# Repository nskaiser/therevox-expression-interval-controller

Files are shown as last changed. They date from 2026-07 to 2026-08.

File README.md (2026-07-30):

# Therevox Expression Controller

Turns an expression pedal input into a programmable Therevox modulation source. In `PED` mode, pick a pitch-bend interval with the rotary encoder and the pedal bends smoothly from no-bend to that interval; in `LO`/`FM` modes, the expression output can become an LFO source. The MCP4728 build also adds two independent 3.5mm LFO outputs for the Therevox patch panel.

Built with:

- Raspberry Pi Pico H
- MCP4728 quad I2C DAC
- 0.91 inch 128x32 I2C OLED
- Rotary encoder with push switch
- Two 1/4 inch TRS jacks: expression pedal in, Therevox expression/CV out
- Two 3.5mm TS jacks: independent LFO 1 and LFO 2 outputs
- USB power

## Start Here

| Need | File |
| --- | --- |
| Arduino firmware | `pico/PrecisionExpressionControllerPico/PrecisionExpressionControllerPico.ino` |
| User/menu manual | `docs/user-manual.md` |
| Therevox sample patches | `docs/sample-patches.md` |
| Wiring and bench test | `docs/pico-prototype.md` |
| Perfboard/enclosure layout | `docs/pico-physical-layout.md` |
| BOM | `docs/bom.md` |
| Console simulator | `sim/pico_console_sim.cpp` |
| 3D-print enclosure files (untested, never printed) | `hardware/enclosure/` |

## How It Works

One bend direction is active at a time for the expression output. Use the menu or serial `direction up|down` to change it.

```text
UP:   heel 0 V, toe rises to the selected interval's voltage
DOWN: heel 3.3 V, toe falls to the selected interval's voltage
```

Tune the instrument with the pedal at heel.

Interval accuracy comes from a per-interval voltage map. Set the overall scale with `response <cents>` (the pitch change your instrument produces at full DAC scale; `3960` for a true 1V/oct input), then fine-tune any interval against a tuner with `tune on`. See `docs/pico-prototype.md` for the full serial command reference.

Note the DAC output tops out at 3.3 V. If your instrument needs more than that for an octave, the largest selectable interval shrinks accordingly.

LFO modes ignore the pedal interval map and output a unipolar `0-3.3V` modulation signal from the DAC. `LO` covers slow LFO rates (`0.05-20 Hz`); `FM` covers faster modulation rates (`8-160 Hz`). On the expression output, the pedal sweeps LFO speed from slow to fast and the encoder adjusts depth. On `LFO1`/`LFO2`, the encoder adjusts speed directly.

LFO features:

- Eight waveforms: sine, triangle, saw up, saw down, square, pulse (adjustable width `5-95%`), sample+hold random, and drift (smoothed random).
- Depth `0-100%` around the midpoint, plus a `-50..+50%` center offset on `LFO1`/`LFO2` (depth `0` + offset = fixed CV).
- `LFO2` can lock to `LFO1` at a rate ratio (`1:1`, `1:2`, `1:4`, `3:2`, `2:1`, `4:1`) with a `0/90/180/270` degree phase offset — quadrature and polyrhythm pairs that never drift.
- Tap tempo: two short presses on a focused LFO sync it and set its rate to the tapped interval.
- `sync` / `sync all` phase resets, per-output polarity.
- The DAC's fourth channel can emit a full-swing clock square at `LFO1` or `LFO2`'s rate (`clock lfo1|lfo2`).

## Build And Upload

1. In Arduino IDE, install the board package `Raspberry Pi Pico/RP2040/RP2350` by Earle F. Philhower.
2. Open `pico/PrecisionExpressionControllerPico/PrecisionExpressionControllerPico.ino`.
3. Select `Tools > Board > Raspberry Pi Pico/RP2040/RP2350 > Raspberry Pi Pico`.
4. Plug in the Pico over USB, select its port, and upload.
5. Open Serial Monitor at `115200`.

If the Pico does not show as a port, unplug it, hold `BOOTSEL`, plug USB back in, release `BOOTSEL`, then upload again.

## Tests

```bash
# Host math test
g++ -std=c++17 test/test_pico_core.cpp -o /tmp/expctrl_test && /tmp/expctrl_test

# Console simulator (expects SIM RESULT: PASS)
g++ -std=c++17 sim/pico_console_sim.cpp -o /tmp/expctrl_sim && /tmp/expctrl_sim

# Firmware compile check
arduino-cli compile --fqbn rp2040:rp2040:rpipico pico/PrecisionExpressionControllerPico
```

## Control Summary

| Action | Result |
| --- | --- |
| Turn encoder with `EXP` focused in `PED` | Change interval size by one semitone |
| Move pedal in expression `LO`/`FM` | Sweep expression-output LFO speed within that mode's range |
| Turn encoder with `EXP` focused in `LO`/`FM` | Change expression-output LFO depth/attenuation in `5%` steps |
| Turn encoder with `LFO1` or `LFO2` focused | Change that dedicated LFO output speed (or phase offset when `LFO2` is linked) |
| Short press in `PED` | Reset interval to unison |
| Short press in `LO`/`FM`, `LFO1`, or `LFO2` | Sync the focused LFO; two presses at tempo tap its rate |
| Double-click | Cycle edit focus: `EXP` -> `LFO1` -> `LFO2` |
| Hold ~2s | Open menu |
| In menu: turn / press / hold ~2s | Scroll items / edit or choose / exit |
| Editing a menu value | Turn to the value you want, then press to save |

Settings autosave about 3s after the last change.

See `docs/user-manual.md` for the full OLED menu reference.

LFO serial shortcuts:

```text
mode ped|lo|fm
focus exp|lfo1|lfo2
wave sine|tri|sawup|sawdown|square|pulse|sh|drift
rate 1.5      set focused LFO speed; EXP LFO uses this as toe/max speed
depth 75      set focused LFO depth, 0..100
pw 60         pulse-wave width, 5..95
offset -25    shift focused LFO1/LFO2 center, -50..50
link 1:2      lock LFO2 rate to LFO1; link phase 90 for quadrature
clock lfo1    full-swing clock square on the DAC's spare channel
sync          sync focused LFO; sync all resets every phase
tap           send twice at tempo to set the focused LFO rate
```

## Project Layout

```text
docs/                  wiring, layout, BOM, product notes
hardware/enclosure/    STL generator and files (untested)
pico/                  Arduino firmware
sim/                   host-side console simulator
test/                  host-side math tests
```

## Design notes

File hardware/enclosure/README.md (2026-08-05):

# 3D Printed Enclosure

> **Untested:** This enclosure design has not been printed or built yet. The STLs are generated from nominal component dimensions and have never been test-fitted against real hardware. Expect to verify every cutout and tolerance yourself. Treat this as a starting point, not a proven design.

First-pass printable enclosure for the Pico/DAC/OLED/rotary-encoder prototype.

Generated files:

```text
stl/expression_controller_baseplate.stl
stl/expression_controller_body.stl
stl/expression_controller_lid.stl
```

The generator is:

```text
generate_enclosure_stl.py
```

## Dimensions

- Outside body footprint: `126 mm x 112 mm`
- Body height: `34 mm`
- Lid thickness: `3 mm`
- Wall thickness: `2.4 mm`
- Fits a Prusa Mini build plate.
- Perfboard footprint: `90 mm x 70 mm`, mounted landscape.
- Open baseplate footprint: `98 mm x 78 mm`, giving `4 mm` margin around the
  perfboard and no side walls or lid.
- Perfboard post height: `7 mm`, so the top of a nominal `1.6 mm` board sits
  about `11 mm` above the enclosure floor.

## Cutouts

- Top lid OLED window: `30 mm x 11.5 mm`
- Top lid rotary encoder hole: `7.4 mm`
- Left/right side TRS jack openings: square `23/32 inch` / `18.26 mm`,
  starting at the perfboard top surface.
- Front 3.5mm LFO jack openings: square `5.72 mm` / `20%` larger than `6/32 inch`, with the
  bottom edge `5/32 inch` / `3.97 mm` above the perfboard top surface.
- Rear USB/service opening: `18 mm x 10 mm`
- Lid screws: `M2.5` clearance holes
- Internal corner posts: `M2.5` pilot holes
- Internal perfboard posts: four short posts for a centered `90 mm x 70 mm` board

The TRS side openings are sized for your square-body 1/4 inch jacks. If your
jacks need a different opening, adjust `TRS_OPENING_W` / `TRS_OPENING_H` in
`generate_enclosure_stl.py` and regenerate.

The 3.5mm front openings are sized from your `5/32 inch` to `11/32 inch`
above-perfboard measurement. If those jacks need a different opening, adjust
`LFO_OPENING_W`, `LFO_OPENING_H`, or `LFO_BOTTOM_Z` in
`generate_enclosure_stl.py` and regenerate.

The perfboard posts use your measured `3 mm` board holes. The hole edge starts
`1.3 mm` from the left/right `70 mm` side edges and `0.6 mm` from the top/bottom
`90 mm` side edges, so the center insets are `2.8 mm` and `2.1 mm`. That gives
`84.4 mm x 65.8 mm` post spacing. The printed pilot holes are `3.2 mm` diameter
for tolerance. If your board measures
differently, adjust `PERFBOARD_MOUNT_HOLE_INSET_X` /
`PERFBOARD_MOUNT_HOLE_INSET_Y` in `generate_enclosure_stl.py` and regenerate.

## Print

Recommended first print:

```text
Material: PLA or PETG
Layer height: 0.20 mm
Perimeters: 3
Infill: 20%
Supports: off, or build-plate-only if your slicer wants support for the rear USB opening
```

Print orientation:

- `expression_controller_baseplate.stl`: flat bottom face on the build plate.
- `expression_controller_body.stl`: bottom face on the build plate, open side upward.
- `expression_controller_lid.stl`: outside/top face upward.

The baseplate is now the preferred raw-build part: it protects the soldered
underside and provides the four perfboard risers without enclosing the controls.
The full body/lid files remain available as older enclosure experiments.

## Intended Layout

```text
Top lid, with the rear USB opening facing away:
  rotary encoder in the rear half
  OLED in the front half

Left side:
  expression pedal TRS input

Right side:
  Therevox CV/output TRS

Front:
  LFO1 and LFO2 3.5mm patch outputs

Rear:
  USB access/service opening
```

For exact perfboard placement, Pico orientation, jack wiring, OLED/encoder wiring, and row/column solder points, see:

```text
../../docs/pico-physical-layout.md
```

## Regenerate

From the repository root:

```bash
python3 hardware/enclosure/generate_enclosure_stl.py
```

The script has no CAD dependencies. It writes ASCII STL files directly.

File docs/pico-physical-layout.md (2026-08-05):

# Pico Physical Layout

This layout is meant to match the generated enclosure in `hardware/enclosure/stl/`.

> **Untested:** The enclosure has not been printed or built yet, so this physical layout is a plan, not a verified build. The bench wiring in `docs/pico-prototype.md` is what has actually been tested.

Use perfboard for the enclosure build. A solderless breadboard is fine for a bench test, but it will not fit cleanly in the printed box and the side jacks/lid controls will pull wires loose.

## Enclosure Orientation

Hold the box so the rear USB opening faces away from you.

```text
Rear / USB side
+----------------------------------------------+
|                 USB opening                  |
|                                              |
|              rotary encoder hole             |
|                                              |
|  expression input TRS      Therevox output   |
|  jack on left side         TRS jack on right |
|                                              |
|                OLED window                   |
|          LFO1 3.5mm      LFO2 3.5mm          |
+----------------------------------------------+
Front / player side
```

The generated enclosure dimensions are:

| Feature | Position |
| --- | --- |
| Body outside | `126mm x 112mm x 34mm` |
| OLED window | lid centerline, front half, `30mm x 11.5mm` |
| Encoder hole | lid centerline, rear half, `7.4mm` diameter |
| Expression input jack | left side wall, centered front/back, square `23/32 inch` / `18.26mm` opening |
| Therevox output jack | right side wall, centered front/back, square `23/32 inch` / `18.26mm` opening |
| LFO1 3.5mm jack | front wall, left of center, square `5.72mm` opening, `20%` larger than the measured `6/32 inch` jack body |
| LFO2 3.5mm jack | front wall, right of center, square `5.72mm` opening, `20%` larger than the measured `6/32 inch` jack body |
| USB/service opening | rear wall, centered left/right |

## Perfboard Size And Placement

Use the full `90mm x 70mm` perfboard, mounted landscape. Do not cut it down.

```text
Board width left/right: 90mm
Board depth rear/front: 70mm
```

Place it on the enclosure floor like this:

- Centered left/right.
- Centered rear/front.
- Long `90mm` edge runs left/right.
- Short `70mm` edge runs rear/front.
- The long horizontal lettering sequence, `A-Z` then restarting at `A`, runs
  left/right.
- The short vertical `A-Z` lettering sequence runs rear/front.
- Pico USB end facing the rear USB opening.
- Mount the four board corner holes over the four short printed perfboard posts.

The generated baseplate uses your measured `3mm` perfboard corner holes. The
hole edge starts `1.3mm` from the left/right `70mm` side edges and `0.6mm` from
the top/bottom `90mm` side edges, so the hole centers are `2.8mm` and `2.1mm`
from those edges. That gives post spacing of:

```text
left/right post spacing: 84.4mm
rear/front post spacing: 65.8mm
```

The Amazon listing confirms the board is `90mm x 70mm`, but it does not publish
the exact corner-hole center offset. Before printing the full box, measure your
actual board. If the hole centers differ, change
`PERFBOARD_MOUNT_HOLE_INSET_X` and `PERFBOARD_MOUNT_HOLE_INSET_Y` in
`hardware/enclosure/generate_enclosure_stl.py` and regenerate the STL files.

Do not mount the OLED or encoder to the perfboard. They mount to the lid/panel and connect with flexible hookup wires.

## Perfboard Coordinate System

View the perfboard from above with the USB opening at the top. The exact
printed labels vary by board side; the mechanical STL only depends on the
`90mm x 70mm` outline and corner mounting holes.

```text
Rear / USB side

left/right: 90mm long edge
rear/front: 70mm short edge

Front / player side
```

The plan below assumes:

- The long `90mm` edge runs left/right.
- The short `70mm` edge runs rear/front.
- Pico USB faces the rear USB opening.
- The board is centered over the four printed perfboard posts.

## Step-By-Step Perfboard Transfer

Use this order when moving the tested breadboard circuit onto perfboard. Keep
the board loose until the electrical tests pass, then mount it in the printed
body.

1. Dry-fit the empty perfboard in the printed body.
   - Long `90mm` edge runs left/right.
   - Short `70mm` edge runs rear/front.
   - Pico USB will face the rear USB opening.
   - The four corner holes should sit over the four printed perfboard posts.

2. Put the Pico H on the perfboard, but do not solder every pin yet.
   - Pico USB connector points toward row `1` / rear USB opening.
   - Pico physical pin `1` sits at row `4`, column `J`.
   - Pico physical pin `20` sits at row `23`, column `J`.
   - Pico physical pin `40` sits at row `4`, column `Q`.
   - Pico physical pin `21` sits at row `23`, column `Q`.
   - Dry-fit the perfboard in the enclosure with a USB cable plugged in before
     soldering the Pico permanently.

3. Make the two underside power buses.
   - `3V3` bus: row `29`, columns `B-Y`.
   - `GND` bus: row `30`, columns `B-Y`.
   - Connect Pico `3V3(OUT)`, physical pin `36`, row `8` column `Q`, to row `29`.
   - Connect Pico `GND`, physical pin `38`, row `6` column `Q`, to row `30`.
   - Connect Pico `GND`, physical pin `33`, row `11` column `Q`, to row `30`.
   - Before adding modules, power from USB and verify row `29` to row `30` is
     about `3.3V`.

4. Build the I2C fanout at the left rear.
   - Bridge row `4`, columns `B-D` for `3V3`.
   - Bridge row `5`, columns `B-D` for `GND`.
   - Bridge row `6`, columns `B-D` for `SDA`.
   - Bridge row `7`, columns `B-D` for `SCL`.
   - Wire row `6` fanout to Pico `GP4`, physical pin `6`, row `9` column `J`.
   - Wire row `7` fanout to Pico `GP5`, physical pin `7`, row `10` column `J`.
   - Wire row `4` fanout to the row `29` `3V3` bus.
   - Wire row `5` fanout to the row `30` `GND` bus.

5. Move the expression input circuit.
   - Input TRS Sleeve goes to `GND` bus row `30`, column `C`.
   - Input TRS Ring goes to `3V3` bus row `29`, column `C`.
   - Input TRS Tip goes to row `13`, column `B`.
   - Put the `1k` input resistor from row `13`, column `B` to row `13`, column `P`.
   - Bridge row `13`, columns `P-Q`; row `13`, column `Q` is Pico `GP26/ADC0`.
   - Put the `100nF` capacitor from row `13`, column `P` to row `11`, column `P`.
   - Bridge row `11`, columns `P-Q`; row `11`, column `Q` is Pico `GND` pin `33`.

6. Wire the MCP4728 quad DAC.
   - DAC `V` goes to the `3V3` fanout.
   - DAC `S` goes to the `GND` fanout; this board's ground pin is printed `S`.
   - DAC `DA` goes to the `SDA` fanout.
   - DAC `CL` goes to the `SCL` fanout.
   - DAC `L` goes to the `GND` bus.
   - DAC `R` is left unconnected.
   - DAC `A` goes to row `14`, column `S`.
   - DAC `B` goes to row `16`, column `S`.
   - DAC `C` goes to row `18`, column `S`.
   - DAC `D` is optional clock output; leave it unconnected unless you add a
     third 3.5mm jack.

7. Wire the output jacks.
   - Put a `1k` resistor from row `14`, column `S` to row `14`, column `Y`.
   - Therevox output physical Tip goes to row `14`, column `Y`.
   - Therevox output Sleeve goes to `GND` bus row `30`, column `Z`.
   - Therevox output Ring is left unconnected.
   - Put a `1k` resistor from row `16`, column `S` to row `16`, column `Y`.
   - LFO1 3.5mm Tip goes to row `16`, column `Y`.
   - LFO1 Sleeve goes to `GND` bus row `30`, column `X`.
   - Put a `1k` resistor from row `18`, column `S` to row `18`, column `Y`.
   - LFO2 3.5mm Tip goes to row `18`, column `Y`.
   - LFO2 Sleeve goes to `GND` bus row `30`, column `Y`.

8. Wire the lid controls with flexible wire slack.
   - OLED red goes to `3V3` fanout.
   - OLED black goes to `GND` fanout.
   - OLED blue goes to `SDA` fanout.
   - OLED yellow goes to `SCL` fanout.
   - Encoder `C` / common goes to `GND`.
   - Encoder `A` / CLK goes to Pico `GP14`, physical pin `19`, row `22` column `J`.
   - Encoder `B` / DT goes to Pico `GP15`, physical pin `20`, row `23` column `J`.
   - One encoder switch lug goes to Pico `GP13`, physical pin `17`, row `20` column `J`.
   - The other encoder switch lug goes to `GND`.

9. Test before final mounting.
   - With USB power only, verify `3V3` to `GND` is about `3.3V`.
   - Verify input Ring to Sleeve is about `3.3V`.
   - Verify the OLED boots and the encoder changes values.
   - Verify serial reports MCP4728 pass at `0x60` and OLED pass at `0x3C`.
   - Run fixed CV tests before plugging into the Therevox: `cv 0`, `cv 1000`,
     and `cv 3200`, measuring output physical Tip to Sleeve.
   - Only after those checks pass, mount the perfboard to the printed posts and
     add strain relief to the jack and lid wires.

## Pico Placement

Put the Pico H on the perfboard first.

```text
Pico USB connector points toward row 1 / rear USB opening.

Pico physical pin 1  -> row 4,  column J
Pico physical pin 20 -> row 23, column J

Pico physical pin 40 -> row 4,  column Q
Pico physical pin 21 -> row 23, column Q
```

That puts the Pico's two header rows `7` columns apart, which matches the Pico's `0.7 inch` row spacing on 0.1 inch perfboard.

Useful Pico pins in this layout:

| Signal | Pico label | Physical pin | Perfboard hole |
| --- | --- | ---: | --- |
| `SDA` | `GP4` | `6` | row `9`, column `J` |
| `SCL` | `GP5` | `7` | row `10`, column `J` |
| Encoder switch | `GP13` | `17` | row `20`, column `J` |
| Encoder A / CLK | `GP14` | `19` | row `22`, column `J` |
| Encoder B / DT | `GP15` | `20` | row `23`, column `J` |
| Pedal ADC | `GP26/ADC0` | `31` | row `13`, column `Q` |
| Local ADC ground | `GND` | `33` | row `11`, column `Q` |
| 3.3V rail feed | `3V3(OUT)` | `36` | row `8`, column `Q` |
| Main ground rail feed | `GND` | `38` | row `6`, column `Q` |

## Power Rails On Perfboard

Perfboard holes are not connected unless you solder them.

On the underside, make two bare-wire buses:

| Bus | Perfboard location |
| --- | --- |
| `3V3` | row `29`, columns `B` through `Y` |
| `GND` | row `30`, columns `B` through `Y` |

Then wire:

| From | To |
| --- | --- |
| Pico `3V3(OUT)`, physical pin `36`, row `8` column `Q` | `3V3` bus, row `29` |
| Pico `GND`, physical pin `38`, row `6` column `Q` | `GND` bus, row `30` |
| Pico `GND`, physical pin `33`, row `11` column `Q` | `GND` bus, row `30` |

## I2C Fanout For OLED And DAC

Make a small fanout area on the left rear of the perfboard. This gives you easy solder points for both STEMMA cables.

| Fanout signal | Perfboard tie point | Connects to |
| --- | --- | --- |
| `3V3` | row `4`, columns `B-D` bridged | `3V3` bus |
| `GND` | row `5`, columns `B-D` bridged | `GND` bus |
| `SDA` | row `6`, columns `B-D` bridged | Pico `GP4`, physical pin `6`, row `9` column `J` |
| `SCL` | row `7`, columns `B-D` bridged | Pico `GP5`, physical pin `7`, row `10` column `J` |

Solder the OLED STEMMA cable pigtail and the MCP4728 I2C/power wires to this fanout:

| Signal / OLED STEMMA wire | Fanout signal |
| --- | --- |
| Red | `3V3` |
| Black | `GND` |
| Blue | `SDA` |
| Yellow | `SCL` |

The OLED cable goes to the OLED on the lid. The MCP4728 DAC uses the same four I2C/power signals from this fanout through its `V`, `S`, `DA`, and `CL` header pins. The DAC ground pin is printed as `S`; there may not be a separate `GND` label on the breakout.

## Expression Input Jack

Panel-mount the expression pedal jack in the left side hole.

Use these perfboard tie points:

| Jack lug / part | Perfboard tie point |
| --- | --- |
| Input TRS Sleeve | `GND` bus, row `30`, column `C` |
| Input TRS Ring | `3V3` bus, row `29`, column `C` |
| Input TRS Tip wire | row `13`, column `B` |
| `1k` input resistor | row `13`, column `B` to row `13`, column `P` |
| GP26 input node | bridge row `13`, columns `P-Q` |
| `100nF` capacitor leg 1 | GP26 input node, row `13`, column `P` |
| `100nF` capacitor leg 2 | local ground island, row `11`, column `P` |
| Local ground island | bridge row `11`, columns `P-Q`; row `11`, column `Q` is Pico `GND` pin `33` |

This gives the pedal input the same circuit as the schematic:

```text
Input TRS Tip ---- 1k ---- Pico GP26/ADC0
                           |
                         100nF
                           |
Input TRS Sleeve --------- GND

Input TRS Ring ----------- Pico 3V3(OUT)
```

## DAC And Output Jacks

Panel-mount the Therevox output jack in the right side hole.

Panel-mount the `LFO1` and `LFO2` 3.5mm jacks in the front wall. If those jacks are TRS, use only `Tip` and `Sleeve`; leave `Ring` unconnected.

Mount the MCP4728 breakout near the right/front side of the enclosure, close to the output jacks. It can sit on the perfboard right side or on the enclosure floor with foam tape/standoffs. Its I2C/power pins connect as `V` -> `3V3`, `S` -> `GND`, `DA` -> `SDA`, and `CL` -> `SCL`; again, `S` is the DAC board's ground pin. Also tie the breakout's `L` / `LDAC` pin to the `GND` bus; a floating `LDAC` can freeze all four analog outputs even though I2C writes succeed. Leave `R` / `RDY` unconnected.

The I2C wiring does not carry the DAC outputs, so add these separate wires:

| DAC / output part | Perfboard tie point |
| --- | --- |
| MCP4728 `A` wire | row `14`, column `S` |
| `1k` expression output resistor | row `14`, column `S` to row `14`, column `Y` |
| Therevox output plug physical Tip wire | row `14`, column `Y` |
| Output plug physical Ring | leave unconnected for active external CV |
| Output TRS Sleeve | `GND` bus, row `30`, column `Z` |
| MCP4728 `B` wire | row `16`, column `S` |
| `1k` LFO1 resistor | row `16`, column `S` to row `16`, column `Y` |
| LFO1 3.5mm Tip wire | row `16`, column `Y` |
| LFO1 3.5mm Sleeve | `GND` bus, row `30`, column `X` |
| MCP4728 `C` wire | row `18`, column `S` |
| `1k` LFO2 resistor | row `18`, column `S` to row `18`, column `Y` |
| LFO2 3.5mm Tip wire | row `18`, column `Y` |
| LFO2 3.5mm Sleeve | `GND` bus, row `30`, column `Y` |
| MCP4728 `L` wire | `GND` bus, row `30` |
| MCP4728 `R` | leave unconnected |
| MCP4728 `D` | optional: `1k` to a spare 3.5mm clock jack (`clock lfo1|lfo2`); otherwise leave unconnected |

Output circuit:

```text
MCP4728 A ---- 1k ---- Therevox output plug physical Tip
Output TRS Sleeve -------- GND

Output plug physical Ring - not connected

MCP4728 B ---- 1k ---- LFO1 3.5mm Tip
LFO1 Sleeve --------------- GND

MCP4728 C ---- 1k ---- LFO2 3.5mm Tip
LFO2 Sleeve --------------- GND
```

## Rotary Encoder

Panel-mount the encoder in the lid hole. Leave enough wire slack to open the lid.

The PEC11 body has:

```text
3 small pins on one side      = encoder rotation pins: A, C, B
2 small pins on opposite side = pushbutton switch
1 large lug on each side      = mechanical mounting tabs
```

On the 3-pin side, the middle pin is `C` / common. The two outside pins are `A` and `B`.

| Encoder lug | Pico destination |
| --- | --- |
| `C` / common | `GND` bus |
| `A` / CLK | Pico `GP14`, physical pin `19`, row `22` column `J` |
| `B` / DT | Pico `GP15`, physical pin `20`, row `23` column `J` |
| Switch lug | Pico `GP13`, physical pin `17`, row `20` column `J` |
| Other switch lug | `GND` bus |
| Large side lugs | no electrical connection; solder only for mechanical strength on perfboard |

If clockwise turns the interval down instead of up, swap encoder `A` and `B`.

## OLED

Mount the OLED behind the lid window.

- OLED PCB long direction runs left/right.
- Display glass/window centered in the printed lid opening.
- STEMMA connector/wire exits toward the rear or side, whichever gives the cleanest slack.
- Leave enough cable slack to open the lid without pulling the OLED or Pico.

The OLED connects only through the STEMMA cable fanout described above.

## Breadboard Approximation

For a bench-only breadboard test:

1. Put the Pico across the center trench with USB at the top/rear.
2. Use the breadboard red rail as `3V3` from Pico `3V3(OUT)`.
3. Use the breadboard blue/black rail as `GND` from a Pico `GND`.
4. Put the expression input parts on the left side of the breadboard.
5. Put the MCP4728/output parts on the right/front side.
6. Keep OLED and encoder on loose jumper wires in the same left/right/front/rear orientation as the enclosure.

Do not try to mount the breadboard in the enclosure. Once the circuit works, transfer it to the perfboard layout above.

## Mechanical Checklist

Before final soldering:

- Before printing the full enclosure or baseplate, measure the perfboard corner
  mounting-hole centers. If they are not `84.4mm x 65.8mm` apart, update
  `PERFBOARD_MOUNT_HOLE_INSET_X` / `PERFBOARD_MOUNT_HOLE_INSET_Y` in the
  enclosure generator and regenerate.
- Dry-fit the Pico/perfboard in the enclosure with the USB cable plugged in.
- Confirm the side jack lugs do not touch the perfboard or Pico.
- Confirm the encoder body clears the Pico and wires when the lid is closed.
- Confirm the OLED PCB clears the encoder nut/washer.
- Add strain relief: small zip tie, hot glue, or heat shrink on wires that go to jacks and lid controls.
- Verify with a multimeter before connecting the Therevox:
  - `3V3` bus to `GND`: about `3.3V`.
  - Input TRS Ring to Sleeve: about `3.3V`.
  - Output plug physical Tip to Sleeve at `interval 9`, heel: about `0.000V`.
  - Output plug physical Tip to Sleeve at `interval 9`, toe: about `3.214V`.
  - Output plug physical Tip to Sleeve at `interval -9`, heel: about `3.300V`.
  - Output plug physical Tip to Sleeve at `interval -9`, toe: about `0.086V`.
  - LFO1 Tip to Sleeve: moving voltage between about `0V` and `3.3V`.
  - LFO2 Tip to Sleeve: moving voltage between about `0V` and `3.3V`.

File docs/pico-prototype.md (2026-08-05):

# Pico H Prototype

This is the cheaper soldered prototype build: Raspberry Pi Pico H, MCP4728 quad DAC, 128x32 OLED, one rotary encoder with push, two 1/4 inch TRS jacks, and two 3.5mm dedicated LFO output jacks.

## Important Voltage Model

This firmware uses one bend direction at a time for the expression output. That gives the active direction the full MCP4728 channel-A output range.

```text
UP mode:
  heel/no-bend: 0.000 V
  toe major 6th: 3.214 V with the current response fit

DOWN mode:
  heel/no-bend: 3.300 V
  toe major 6th: 0.086 V with the current response fit
```

Tune the Therevox with the expression pedal heel-down in the active direction. Use the OLED menu `DIR/POL` item or serial `direction up|down` to change `UP`/`DOWN`.

Important hardware limitation: the current output is an active `0-3.3V` DAC signal. For a standard Therevox external-CV test, that voltage should be on the physical plug `Tip` relative to physical plug `Sleeve`. If your jack breakout only bends when you swap its `Tip` and `Ring` lugs, verify with a meter at the actual plug contacts; do not rely only on the breakout silkscreen.

## Parts

| Item | Qty | Notes |
| --- | ---: | --- |
| Raspberry Pi Pico H | 1 | Adafruit PID 5525 |
| MCP4728 quad DAC breakout | 1 | DIYmall GY-MCP4728 or equivalent, I2C address `0x60` |
| Adafruit 0.91 inch 128x32 I2C OLED | 1 | PID 4440, I2C address `0x3C` |
| STEMMA QT / Qwiic JST-SH to male headers cable | 1 | PID 4209, for OLED |
| Rotary Encoder + Extras | 1 | Adafruit PID 377 |
| 1/4 inch TRS jack | 2 | Expression pedal input and Therevox expression/CV output |
| 3.5mm TS or TRS jack | 2 | Dedicated `LFO1` and `LFO2` patch-panel outputs |
| `1k` resistor | 4 | One pedal input series resistor, plus one series resistor per DAC output |
| `100nF` capacitor | 1 | Pedal input noise filter |
| Perfboard | 1 | Better than breadboard for Therevox testing |
| Hookup wire | as needed | `22-24 AWG` solid or stranded |
| USB micro cable / USB power bank | 1 | Do not feed 9V into USB |

## Pico Pin Wiring

Use the Pico H labels printed on the board.

For exact perfboard row/column placement that matches the printed enclosure, use `docs/pico-physical-layout.md`.

### Expression Pedal Input TRS Jack

| Jack lug | Pico H pin | Notes |
| --- | --- | --- |
| Tip | `GP26/ADC0`, physical pin `31` | Connect through a `1k` resistor |
| Ring | `3V3(OUT)`, physical pin `36` | Pedal reference voltage |
| Sleeve | `GND`, physical pin `38` | Common ground |

```text
Input TRS Tip ---- 1k ---- Pico GP26/ADC0
                           |
                         100nF
                           |
Input TRS Sleeve --------- GND

Input TRS Ring ----------- Pico 3V3(OUT)
```

### I2C Bus Shared by DAC and OLED

The OLED STEMMA cable and the MCP4728 header pins connect to the same Pico I2C pins.

Your MCP4728 board labels are shortened. The ground pin on this breakout is
printed as `S`; do not look for a separate `GND` pin on the DAC board.

| MCP4728 board pin | Full name | Connect to |
| --- | --- | --- |
| `V` | VDD / VCC | Pico `3V3(OUT)`, physical pin `36` |
| `S` | Ground / VSS; pin is printed `S` | Pico `GND`, physical pin `38` |
| `CL` | SCL / I2C clock | Pico `GP5`, physical pin `7` |
| `DA` | SDA / I2C data | Pico `GP4`, physical pin `6` |
| `L` | LDAC / latch | GND |
| `R` | RDY/BSY status | leave unconnected |
| `A` | DAC channel A output | expression output, through `1k` |
| `B` | DAC channel B output | `LFO1`, through `1k` |
| `C` | DAC channel C output | `LFO2`, through `1k` |
| `D` | DAC channel D output | optional clock output, through `1k`; otherwise leave unconnected |

The OLED STEMMA cable stays:

| OLED STEMMA wire | Pico H pin |
| --- | --- |
| Red / VCC | `3V3(OUT)`, physical pin `36` |
| Black / GND | `GND`, physical pin `38` |
| Blue / SDA | `GP4`, physical pin `6` |
| Yellow / SCL | `GP5`, physical pin `7` |

**Wire the MCP4728 `L` pin to `GND`.** If `L` / `LDAC` floats high, the chip
accepts every I2C write but can hold the analog outputs frozen — the firmware
uses latch-safe multi-write commands as a backstop, but grounding `LDAC` removes
the failure mode entirely.

This is normal I2C sharing. The MCP4728 DAC is `0x60`; the OLED is `0x3C`.

### MCP4728 DAC Outputs

The I2C cable/header wiring does not carry the DAC outputs. Add regular hookup wires from the DAC output pins to the output jacks:

```text
MCP4728 A ---- 1k ---- Therevox expression output plug physical Tip
Output TRS Sleeve -------- GND
Output plug physical Ring - not connected

MCP4728 B ---- 1k ---- LFO1 3.5mm jack Tip
LFO1 Sleeve --------------- GND

MCP4728 C ---- 1k ---- LFO2 3.5mm jack Tip
LFO2 Sleeve --------------- GND

MCP4728 D ---- 1k ---- optional clock 3.5mm jack Tip (see `clock` command)
Clock jack Sleeve --------- GND
Leave `D` unconnected if you do not need the clock output.
```

Do not use the old optional `100k` pulldown or any temporary `10k` to `11k`
load resistor on any output jack for this active-CV test.

If the 3.5mm jacks are TRS instead of TS, use `Tip` and `Sleeve` only. Leave `Ring` unconnected.

### Replacing the Old Single DAC

Old MCP4725 wiring:

```text
MCP4725 VCC  -> Pico 3V3(OUT), physical pin 36
MCP4725 GND  -> Pico GND, physical pin 38
MCP4725 SDA  -> Pico GP4, physical pin 6
MCP4725 SCL  -> Pico GP5, physical pin 7
MCP4725 VOUT -> 1k -> Therevox output physical Tip
Output Sleeve -> GND
Output Ring   -> not connected
```

New MCP4728 wiring:

```text
MCP4728 V  -> Pico 3V3(OUT), physical pin 36
MCP4728 S  -> Pico GND, physical pin 38  (this DAC pin is printed `S`)
MCP4728 DA -> Pico GP4, physical pin 6
MCP4728 CL -> Pico GP5, physical pin 7
MCP4728 L  -> GND
MCP4728 R  -> not connected

MCP4728 A  -> 1k -> Therevox output physical Tip
Output Sleeve -> GND
Output Ring   -> not connected

MCP4728 B  -> 1k -> LFO1 3.5mm Tip
LFO1 Sleeve -> GND

MCP4728 C  -> 1k -> LFO2 3.5mm Tip
LFO2 Sleeve -> GND

MCP4728 D  -> leave unconnected, or 1k -> optional clock jack Tip
Clock Sleeve -> GND
```

Your Nektar NX-P resistance measurements showed:

```text
Tip-Sleeve: about 11k at heel and toe
Ring-Sleeve: about 0.574k to 11.6k
Tip-Ring: about 11.6k to 0.578k
```

That means `Tip` and `Sleeve` look like the fixed pot ends, and `Ring` looks like the wiper when the NX-P is measured by itself. For active external CV, the Therevox manual identifies the expression jack as `Tip = CV`, `Ring = Reference`, `Sleeve = Ground`. So the active DAC voltage should land on the physical `Tip`.

If swapping `Tip` and `Ring` on your jack breakout is the only way to get bending, that likely means the breakout lug naming, cable, or jack contact path is not what we assumed. The meter test that matters is at the actual plug inserted into the Therevox: `cv 1000` should put about `1.000V` on physical `Tip` to physical `Sleeve`.

### Nektar NX-P Pedal Notes

The Nektar NX-P has a fixed TRS cable, a polarity switch, and a sensitivity pot. Do all measurements with the polarity switch and sensitivity knob in the exact positions that give a clean octave when plugged directly into the Therevox.

With the NX-P unplugged, measure resistance at the pedal plug:

```text
Tip-Sleeve, heel and toe
Ring-Sleeve, heel and toe
Tip-Ring, heel and toe
```

The pair that stays roughly constant is the total pedal pot/load. The two measurements that change identify the wiper. For your measured NX-P setup, `Ring` is the wiper.

### Rotary Encoder

The PEC11 encoder has three different kinds of metal connections:

```text
3 small pins on one side      = encoder rotation pins: A, C, B
2 small pins on opposite side = pushbutton switch
1 large lug on each side      = mechanical mounting tabs
```

Looking at the 3-pin side, the middle pin is `C` / common. The two outside pins are `A` and `B`.

| Encoder lug | Pico H pin |
| --- | --- |
| `C` / common | `GND` |
| `A` / CLK | `GP14`, physical pin `19` |
| `B` / DT | `GP15`, physical pin `20` |
| Switch lug | `GP13`, physical pin `17` |
| Other switch lug | `GND` |
| Large side lugs | no electrical connection |

No resistors are needed. The firmware uses internal pullups. If turning clockwise moves down instead of up, swap encoder `A` and `B`.

## Firmware

Open this sketch in Arduino IDE:

```text
pico/PrecisionExpressionControllerPico/PrecisionExpressionControllerPico.ino
```

Install/select:

```text
Board package: Raspberry Pi Pico/RP2040/RP2350 by Earle F. Philhower
Board: Raspberry Pi Pico
Port: the Pico serial port
Serial Monitor: 115200 baud
```

The local smoke compile passed with:

```text
arduino-cli compile --fqbn rp2040:rp2040:rpipico pico/PrecisionExpressionControllerPico
```

Flashing over the previous release keeps your pedal calibration and tuned toe
map: the firmware migrates stored settings from the last layout (version 11)
and only falls back to defaults from anything older. New settings (pulse width,
offset, link, clock) start at their defaults after migration.

## Bench Smoke Test

Do this before connecting the Therevox.

Before the hardware arrives, run the Mac-side simulator:

```text
g++ -std=c++17 sim/pico_console_sim.cpp -o /tmp/expctrl_pico_console_sim
/tmp/expctrl_pico_console_sim
```

It prints simulated Serial Monitor output, OLED text, DAC millivolts, and DAC codes. It exits with `SIM RESULT: PASS` only after verifying one-direction UP/DOWN rails, MCP4728-style `EXP`/`LFO1`/`LFO2` DAC state, encoder steps, calibration, autosave, and bench idle-sleep disabled.

1. Power the Pico from USB.
2. Open Serial Monitor at `115200`.
3. Confirm boot says:

```text
MCP4728 PASS at 0x60
SSD1306 PASS at 0x3C
```

4. Put a multimeter black probe on the Therevox output plug physical Sleeve and red probe on the output plug physical Tip.
5. Send `interval 9`; heel should be about `0.000V`, toe about `3.214V`.
6. Send `interval -9`; heel should be about `3.300V`, toe about `0.086V`.
7. Send `center`; output should stay at the active direction's heel/no-bend rail.
8. Move the red probe to the `LFO1` 3.5mm Tip, with black on Sleeve. You should see voltage moving between about `0V` and `3.3V`.
9. Move the red probe to the `LFO2` 3.5mm Tip. You should also see an independent moving voltage.

Voltage tuning commands:

```text
direction up     heel/no-bend 0.000V, toe bends upward
direction down   heel/no-bend 3.300V, toe bends downward
range 3300       old linear voltage map; disables response fit
mode ped         expression pedal interval mode
mode lo          slow LFO mode, 0.05-20Hz
mode fm          fast LFO/FM mode, 8-160Hz
focus exp        encoder/menu edits the expression output
focus lfo1       encoder/menu edits dedicated LFO1
focus lfo2       encoder/menu edits dedicated LFO2
wave sine        LFO waveform: sine, tri, sawup, sawdown, square, pulse, sh, drift
rate 1.5         set focused LFO speed; EXP LFO uses this as toe/max speed
depth 75         set focused LFO depth/attenuation, 0-100% in 5% steps
pw 60            pulse-wave width, 5-95%
offset -25       shift focused LFO1/LFO2 center voltage, -50..50%
link 1:2         lock LFO2 rate to LFO1; also link phase 0|90|180|270
clock lfo1       full-swing clock square on DAC D; clock off disables
sync             reset focused LFO phase; sync all resets every LFO
tap              send twice at tempo to set the focused LFO rate
response 924     compressed bench response; rebuilds the global map
dac eeprom       program 0V power-on defaults into the MCP4728 (run once)
save             persist the settings
```

Run `dac eeprom` once per MCP4728 board. It stores 0V power-on values in the
DAC's own EEPROM so the jacks stay silent between power-on and firmware boot.

The default is `direction up` and `response 924`, based on your measured compressed active-DAC response. Selectable intervals now stop at `interval 9`, labeled `6` for a major 6th. `response 3960` means standard `1V/oct` behavior because full DAC scale is about `3.3V`, or `3960` cents. `response off` returns to the older linear voltage map.

If all intervals are proportionally small or large, adjust `response`. This build intentionally stops at `6` because your current active path reaches roughly that range.

For precise tuning, start with the global response map. This is one scale factor, not individual note tuning.

```text
response 924      full DAC scale measured as 924 cents; current bench default
response 3960     standard 1V/oct scale for later wiring diagnosis
response off      disable response fit and use old linear voltage range
map show          print all interval toe voltages
map reset         rebuild the map from response/range
map 2 2050        set major 2nd toe voltage to 2.050V
map -2 2750       set downward major 2nd toe voltage to 2.750V
toe 2050          set toe voltage for the currently selected interval
nudge 25          raise current interval toe voltage by 25mV
nudge -25         lower current interval toe voltage by 25mV
tune on           encoder adjusts current interval toe voltage
tune step 25      set encoder tuning step to 25mV
cv 1500           force fixed DAC output for voltage/range testing
cv off            return to normal pedal control
```

Suggested tuner workflow:

1. Send `direction up`, put the pedal heel-down, and tune the Therevox to unison.
2. Send `response 924`, then test `b2`, `2`, `b3`, and `3` with the pedal toe-down.
3. If all intervals are still proportionally flat, lower `response`; if they are sharp, raise `response`.
4. Send `save`.
5. Send `map show` and keep the printed commands. On board cores that print `settings kept in RAM`, `save` does not survive unplugging.

### Hard Therevox Range Test

Do this when intervals are way off, such as `+b3` only moving about one semitone.

This bypasses the expression pedal, pedal calibration, and interval map. It proves whether the active DAC is reaching the Therevox's actual 1V/oct CV input.

1. Connect the output jack to the Therevox.
2. Open Serial Monitor at `115200`.
3. Send:

```text
cv 0
```

4. Tune the Therevox to your base note.
5. Send:

```text
cv 1000
```

6. Read the tuner.

If physical plug `Tip` really carries `1.000V` above physical `Sleeve`, `cv 1000` should be one octave up on a 1V/oct input. If it is not, the output is not reaching the actual CV input path.

Then send:

```text
cv 3300
```

If `cv 3300` is only around a sixth above `cv 0`, the active DAC is not connected to a plain 1V/oct CV input. Re-check the physical plug `Tip`/`Sleeve`, jack lugs `T` versus `TN`, and the Therevox Exp 1 function setting.

When done:

```text
cv off
```

If `cv 1000` is a clean octave, then use `response 3960` for normal 1V/oct behavior. If the active output still behaves like the compressed measurements you sent, use `response 924` while we fix the wiring/output path.

### Live Interval Tune Mode

Use this after the hard range test.

Example for `+b3`:

```text
interval 3
tune step 25
tune on
```

Then:

1. Hold the expression pedal fully toe-down.
2. Watch a tuner.
3. Turn the encoder clockwise for a larger musical interval, counterclockwise for a smaller one. In DOWN mode this lowers the toe voltage.
4. Stop when the tuner says the interval is correct.
5. Short-press the encoder to save and exit tune mode.

For fine tuning:

```text
tune step 5
tune on
```

If you hit `TOE 3300MV` in UP mode and the interval is still flat, that interval is beyond the current hardware's upward voltage range. In DOWN mode, the equivalent lower limit is `TOE 0MV`.

### OLED Main Screen

The normal OLED screen is intentionally stable. It does not show live pedal percent
or live output voltage, because tiny ADC changes can otherwise redraw the OLED and
look like flicker.

```text
6       TOE 3214MV
        RSP 924C
        CRV LIN
UP SAVED
```

Use Serial Monitor `status` or `monitor on` for live `raw`, `ped`, and output
millivolts while debugging.

### OLED Shows Or Flickers `WAKE`

Current bench firmware disables automatic idle sleep. If you still see `WAKE`
without manually sending `sleep`, you are running an older build. Upload the
current sketch again.

In older builds, `WAKE` meant the firmware had gone into sleep and then woke up.
During bench wiring, that usually meant one of these:

- Encoder switch pin `GP13`, physical pin `17`, is accidentally touching `GND`.
- The encoder switch wiring is noisy or on the wrong pins.
- The expression input `GP26/ADC0` is floating because the expression pedal is not plugged in yet.

Quick test:

1. Unplug power.
2. Remove the wire from Pico `GP13`, physical pin `17`.
3. Power back up.
4. Open Serial Monitor at `115200` and send `status`.

Expected button state:

```text
encBtn13=open
```

If it says:

```text
encBtn13=PRESSED
```

then `GP13` is being held to `GND`; fix the encoder switch wiring before continuing.

For a bench test without the expression pedal plugged in, temporarily connect the input node on `GP26/ADC0` to `GND` through the normal `1k` input resistor path so it does not float.

### Rotary Encoder Does Nothing

The encoder rotation pins are only the three small pins on one side of the encoder. The middle pin is `C` / common, and it must go to `GND`.

Correct rotation wiring:

```text
Encoder C/common  -> Pico GND
Encoder A/outside -> Pico GP14, physical pin 19
Encoder B/outside -> Pico GP15, physical pin 20
```

The two small pins on the opposite side are only the pushbutton. They do not detect rotation.

Serial test:

1. Open Serial Monitor at `115200`.
2. Send `enc debug on`.
3. Turn the encoder slowly.

Expected when the Pico sees rotation:

```text
ENC transitions=...
OK interval ...
```

If there are no `ENC transitions` lines while turning, the Pico is not seeing the encoder pins change. Check that `C` is on `GND`, not `3V3`, and that the two outside rotation pins go to `GP14` and `GP15`. If the interval moves the wrong direction, swap `A` and `B`.

Button hold test:

1. Open Serial Monitor at `115200`.
2. Send `btn debug on`.
3. Press and hold the encoder for about `2s`.

Expected:

```text
BTN press
BTN long -> menu open
OK menu open; turn encoder to select, short press to choose, hold to exit
```

If you see `BTN press` and then `BTN release` before two seconds even though you are still holding the encoder down, the switch wiring is loose or bouncing open. If you see no `BTN press`, the switch pin is not reaching Pico `GP13`, physical pin `17`.

If the OLED shows unreadable or flickering text and Serial finds `0x3C` (`display probe`), suspect a loose STEMMA connector, weak ground, weak 3.3V connection, or a bad OLED module. If Serial does not find `0x3C`, the wiring is wrong or the OLED is not powered.

## Controls

For the full OLED menu manual, see `user-manual.md`.

| Action | Result |
| --- | --- |
| Double-click encoder | Cycle edit focus: `EXP` -> `LFO1` -> `LFO2` |
| Turn encoder with `EXP` focused in `PED` | Change interval size by one semitone, up to major 6th |
| Move pedal with `EXP` focused in `LO`/`FM` | Sweep expression-output LFO speed within that mode's range |
| Turn encoder with `EXP` focused in `LO`/`FM` | Change expression-output LFO depth/attenuation in `5%` steps |
| Turn encoder with `LFO1` or `LFO2` focused | Change that dedicated LFO's speed (or phase offset when `LFO2` is linked) |
| Short press encoder in `PED` | Reset interval to unison |
| Short press encoder in `LO`/`FM`, `LFO1`, or `LFO2` | Sync the focused LFO; two presses at tempo tap its rate |
| Hold encoder about `2s` | Open menu |
| In menu, turn encoder | Scroll the visible menu items |
| In menu, short press encoder | Open the shown setting, run `CAL`, toggle `DIR/POL`, or exit on `DONE` |
| Editing a menu value | Turn to the value you want, then short press to save |
| In menu, hold encoder about `2s` | Exit menu |
| Serial `sleep` / `wake` | Manual sleep test only; automatic idle sleep is disabled for bench testing |

Settings autosave about `3s` after the last change.

PED-mode curve choices:

```text
curve linear     current/default feel
curve easeout    smoother near toe; try this first if the bend jumps late
curve square     slower early, faster near toe
curve smooth     softer heel/toe, faster middle
```

LFO modes:

```text
focus exp        edit the expression output
focus lfo1       edit dedicated LFO1 output
focus lfo2       edit dedicated LFO2 output
mode lo          slow LFO, 0.05-20Hz
mode fm          faster modulation, 8-160Hz
mode ped         return to expression-pedal interval mode
wave sine        smooth sine LFO
wave tri         triangle LFO
wave sawup       rising sawtooth
wave sawdown     falling sawtooth
wave square      50% square wave
wave pulse       pulse wave; width set with pw 5..95, default 25%
wave sh          sample+hold: a new random level each cycle
wave drift       smooth glide between random levels
rate 2.5         set focused LFO speed; EXP LFO uses this as toe/max speed
depth 75         set focused LFO depth/attenuation; 0 pins the output at center
pw 60            pulse-wave width for the focused LFO
offset -25       shift focused LFO1/LFO2 center voltage
link 1:2         lock LFO2 rate to half of LFO1's; link off to free-run
link phase 90    linked LFO2 quarter-cycle offset (0|90|180|270)
clock lfo1       clock square on DAC D at LFO1's rate; clock off disables
sync             reset focused LFO phase; sync all resets every LFO
tap              send twice at tempo to set the focused LFO rate
polarity down    invert focused LFO1/LFO2
```

All DAC outputs are unipolar `0-3.3V`. `UP` polarity is normal; `DOWN`
polarity inverts the LFO. Depth is bipolar around the midpoint: at `75%`, a sine
peak is `75%` as far above and below the midpoint as it is at `100%`, and at
`0%` the output sits flat at the midpoint (add `offset` for a fixed CV). The
top of `FM` mode is intentionally rough because the MCP4728 is an I2C DAC, not
a true audio DAC.

Linked LFO2 (`link` other than `off`) derives its phase from LFO1, so ratio
pairs like `1:2` or quadrature (`1:1` + `link phase 90`) stay locked forever;
while linked, LFO2's own `rate` is ignored and the encoder steps the phase
offset instead.

## Pedal Calibration

With the encoder:

1. Hold encoder about `2s` to open the menu.
2. Turn to `CAL`.
3. Short press encoder; the OLED says `HEEL`.
4. Put the expression pedal fully heel-down.
5. Short press encoder.
6. Put the expression pedal fully toe-down.
7. Short press encoder again; calibration is saved.

With Serial Monitor:

```text
cal start
```

Put the expression pedal fully heel-down, then send:

```text
cal heel
```

Put the expression pedal fully toe-down, then send:

```text
cal toe
```

To throw away calibration and return to the full ADC range:

```text
cal reset
```

If pedal direction is backward, send:

```text
invert on
save
```

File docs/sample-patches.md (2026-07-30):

# Sample Patches

Patch ideas for the Therevox ET-5 patch panel using this controller's outputs:

```text
EXP   1/4 inch expression/CV output (pitch-bend intervals, or a third LFO)
LFO1  3.5mm LFO output, DAC channel B
LFO2  3.5mm LFO output, DAC channel C
CLK   optional 3.5mm clock output, DAC channel D (clock lfo1|lfo2)
```

The ET-5 panel's top two rows are `0-5V` CV inputs; the bottom rows are
performance-control outputs. The passive 4-way mults split or combine CVs, and
the middle inverter flips a control's response.

The LFO jacks put out `0-3.3V`, which drives any ET-5 input to about two thirds
of full range. Use `depth` and `offset` to place the modulation window: depth
scales the swing around the midpoint, offset shifts the center up or down.

Serial settings shown below can also be dialed in from the OLED menu.

## With EXP Playing Pitch-Bend Intervals

The pedal owns pitch; LFO1/LFO2 act as a second player.

### Auto-Crossfade Tremolo

```text
LFO1 -> vol 1
LFO2 -> vol 2

focus lfo1
wave sine        (square for hard alternation)
rate 1.5         (or tap twice at tempo)
focus lfo2
link 1:1
link phase 180
```

The two oscillators breathe in opposition, morphing between their timbres while
you bend on top. The link is phase-derived, so the pair never drifts.

### Breathing Filter

```text
LFO2 -> cutoff

focus lfo2
wave drift
rate 0.1
depth 70
```

Drift never repeats a cycle, so the tone slowly evolves under sustained notes.
Swap `wave sh` at a faster rate for stepped random filter jumps.

### Rhythmic Sparkle, Locked Together

```text
LFO1 -> vol 1
LFO2 -> cutoff

focus lfo1
wave pulse
pw 25
rate 2
focus lfo2
wave sh
link 1:2
```

LFO1 chops the volume; every second chop lands on a new random filter color.

### Slow Spatial Swells

```text
LFO2 -> reverb   (or fx mix)

focus lfo2
wave sine
rate 0.05
```

The space around the instrument inhales and exhales over ten to twenty seconds.

### Vibrato On Osc 2 Only

```text
LFO1 -> pitch 2

focus lfo1
wave sine
rate 5.5
depth 10
offset -45
```

Low depth plus a negative offset keeps the swing small and near `0V`, so osc 2
shimmers against a pure osc 1 instead of sounding like a siren.

## With EXP As A Third LFO

Set `mode lo` or `mode fm` on `EXP` and the pedal sweeps that LFO's speed —
a rate pedal.

### Foot-Controlled Rotary Speaker

```text
EXP  -> mult -> vol 1
        mult -> cutoff
LFO1 -> vol 2

focus exp
mode lo
wave sine
focus lfo1
wave sine
link phase 90    (after link 1:1 with LFO2 if used)
```

Heel is a slow throb, toe a fast shimmer, and the pedal ramps between them like
a Leslie spinning up.

### Playable FM Growl

```text
EXP -> fm 1

focus exp
mode fm
wave sine
```

The pedal sweeps `8-160Hz` of rough FM, from slow warble at heel to clangorous
sidebands at toe.

### Quadrature Orbit

```text
LFO1 -> vol 1
LFO2 -> vol 2
EXP  -> fx mix

focus lfo1
wave sine
rate 0.5
focus lfo2
link 1:1
link phase 90
```

At 90 degrees the sound seems to circle between the oscillators rather than
see-saw. The pedal puts motion depth underfoot.

### Interlocking Polyrhythm

```text
LFO1 -> vol 1
LFO2 -> vol 2
CLK  -> external gear clock input

focus lfo1
wave pulse
pw 25
rate 2       (or tap twice at tempo)
focus lfo2
wave pulse
link 3:2
clock lfo1
```

A 3-against-2 pattern between the oscillators that never drifts, with the rest
of the rig locked to the clock jack.

### Self-Evolving Drone

```text
hold 1 -> vol 1        (ET-5 hands-free drone)
LFO1   -> pitch 2
LFO2   -> reson

focus lfo1
wave drift
rate 0.05
depth 15
offset -40
focus lfo2
wave sh
rate 0.2
```

The drone plays itself; you sculpt it from the encoder.

## Utility Tricks

- **Extra knobs**: `depth 0` plus `offset` turns any LFO jack into a fixed CV —
  a set-and-forget level for `reson` or `fx mix`.
- **Complementary motion**: run one LFO through the panel inverter to a second
  destination — for example bright-but-dry / dark-but-wet from a single source.
- **Sync as a gesture**: `sync all` (or a short press per output) restarts every
  waveform together — useful at section changes.

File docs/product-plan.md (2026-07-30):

# Product Plan

## Goal

Build a programmable expression controller that lets a musician choose musical bend ranges instead of trimming an expression pedal by percentage.

The current target is a Raspberry Pi Pico H prototype with:

- TRS expression pedal input
- Rotary encoder with push switch
- 128x32 OLED
- MCP4728 quad DAC CV output
- One expression/CV output plus two dedicated 3.5mm LFO outputs
- USB power
- 3D-printed enclosure

## Prototype Scope

Features implemented:

- Pico H ADC read from expression pedal on `GP26/ADC0`.
- Heel/toe calibration from the encoder menu.
- One-direction CV model capped at a major 6th for this bench build. `UP` uses `0.000 V` heel/no-bend to about `3.214 V` toe with the current response fit; `DOWN` uses `3.300 V` heel/no-bend to about `0.086 V` toe.
- Output modes: `PED` expression interval mode, `LO` slow LFO mode, and `FM` faster modulation mode.
- LFO waveforms: sine, triangle, saw up, saw down, square, pulse (adjustable `5-95%` width), sample+hold random, drift (smoothed random).
- LFO `LO` range: `0.05-20 Hz`; LFO `FM` range: `8-160 Hz`.
- LFO depth `0-100%` around the midpoint, plus `-50..+50%` center offset on `LFO1`/`LFO2` (depth `0` + offset acts as a fixed CV source).
- `LFO2` can link to `LFO1` at `1:1`, `1:2`, `1:4`, `3:2`, `2:1`, or `4:1` with a `0/90/180/270` degree phase offset, drift-free.
- Tap tempo (two presses on a focused LFO), per-LFO sync, and `sync all`.
- MCP4728 DAC CV output over I2C on `GP4/SDA` and `GP5/SCL`, using latch-safe multi-write commands that assert `VREF=VDD`/`gain=1` on every update; `dac eeprom` programs silent 0V power-on defaults.
- DAC channel A drives the expression/CV output; channels B and C drive dedicated `LFO1` and `LFO2`; channel D can emit a full-swing clock square at `LFO1`/`LFO2` rate.
- Stored-settings migration: upgrading from the previous settings layout preserves calibration and the tuned toe map.
- 128x32 SSD1306 OLED on the same I2C bus.
- Rotary encoder on `GP14`/`GP15`; push switch on `GP13`.
- Short encoder press resets interval to unison.
- Double-click encoder cycles edit focus: `EXP`, `LFO1`, `LFO2`.
- Encoder hold about `2s` opens an OLED menu.
- OLED menu can choose output focus, change mode, waveform, depth, curve, start calibration, toggle direction/polarity, or close. LFO-only items are hidden when the expression output is in normal `PED` mode.
- Pedal curve modes: linear, easeout, square, smooth.
- Automatic idle sleep is disabled during bench testing to avoid OLED blank/wake flicker.
- Autosave about `3s` after interval/calibration changes.
- Serial UI for setup, calibration, monitoring, and I2C probes.
- Mac-side simulator for OLED/Serial/DAC behavior.

Acceptance criteria:

- Arduino sketch compiles for `rp2040:rp2040:rpipico`.
- Simulator exits with `SIM RESULT: PASS`.
- Serial boot detects MCP4728 at `0x60` and SSD1306 at `0x3C` once wired.
- Pedal reads smoothly from `0.0000` to `1.0000` after calibration.
- `interval 9` measures about `0.000 V` at heel and `3.214 V` at toe.
- `interval -9` measures about `3.300 V` at heel and `0.086 V` at toe.
- Rotary encoder steps exactly one semitone of interval size per detent.
- Short press resets to unison or syncs the focused LFO; double-click cycles edit focus; long press opens the OLED menu.
- In `LO`/`FM`, the expression pedal sweeps LFO speed and the rotary encoder changes LFO depth.
- `LO`/`FM` outputs remain `0-3.3V`, support all six LFO waveforms, and support `50-100%` depth/attenuation.
- Dedicated `LFO1` and `LFO2` outputs can run independently while the expression output stays in `PED` mode.

## Later Product Questions

- Whether MCP4728 resolution is enough musically, or whether a higher-precision DAC is needed.
- Whether a future true audio-rate modulation output needs a faster DAC or PWM/filter output instead of MCP4728 I2C.
- Bench result: the active output reaches about a sixth even when firmware requests more and the output measures about `3.2V`. This build accepts that limit for now and remaps intervals so `6` is accurate.
- Decide whether the prototype should use true active 1V/oct CV on physical Tip/Sleeve or a passive expression-pedal emulator that matches the Nektar NX-P behavior.
- Whether to keep the OLED or switch to a simpler segment display after debug needs are gone.
- Whether to add true hardware power-off instead of firmware sleep.
- Whether to support passive expression emulation or MIDI in a separate product variant.

## Commercialization Checklist

- Reverse-polarity and overvoltage protection.
- ESD protection on external jacks.
- Output current limiting.
- Power-up and brownout behavior verified on scope.
- Factory reset path.
- Firmware update path.
- Calibration procedure written for production.
- Enclosure layout with jack/control spacing validated.
- Clear compatibility matrix by device type and expression standard.

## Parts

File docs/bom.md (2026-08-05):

# BOM

This is the active Pico H prototype BOM.

| Item | Qty | Notes |
| --- | ---: | --- |
| Raspberry Pi Pico H | 1 | Adafruit PID 5525, headers already soldered |
| MCP4728 quad I2C DAC breakout | 1 | DIYmall GY-MCP4728 or equivalent, default address `0x60` |
| Adafruit 0.91 inch 128x32 I2C SSD1306 OLED | 1 | PID 4440, default address `0x3C` |
| STEMMA QT / Qwiic JST-SH to male headers cable | 1 | For OLED |
| Rotary Encoder + Extras | 1 | Adafruit PID 377 |
| 1/4 inch TRS jack/breakout | 2 | One expression pedal input, one Therevox expression/CV output |
| 3.5mm TS or TRS jack | 2 | Dedicated `LFO1` and `LFO2` patch outputs; leave Ring unconnected on TRS jacks |
| 3.5mm TS or TRS jack | 1 (optional) | Clock output from MCP4728 `D` |
| `1k` resistor | 4 minimum, 5 with optional clock | Input Tip series resistor plus DAC `A`, `B`, and `C`; add one more for optional DAC `D` clock output |
| `100nF` ceramic capacitor | 1 | Pico `GP26/ADC0` input filter to `GND` |
| Solderable perfboard | 1 | Use for the enclosure build |
| Hookup wire | as needed | `22-24 AWG`; use separate wires for MCP4728 `A`, `B`, and `C` |
| USB micro cable | 1 | For programming and power |
| USB power bank | 1 | Recommended portable power source |
| M2.5 screws/standoffs or printed posts | as needed | For mounting perfboard/enclosure |

The I2C wiring does not carry the DAC outputs. Wire these separately:

```text
MCP4728 V  -> Pico 3V3(OUT), physical pin 36
MCP4728 S  -> Pico GND, physical pin 38  (this DAC pin is printed `S`, not `GND`)
MCP4728 DA -> Pico GP4/SDA, physical pin 6
MCP4728 CL -> Pico GP5/SCL, physical pin 7
MCP4728 L  -> Pico GND (required; outputs can freeze if LDAC floats)
MCP4728 R  -> leave unconnected
MCP4728 A  -> 1k -> Therevox expression output plug physical Tip
MCP4728 B  -> 1k -> LFO1 3.5mm jack Tip
MCP4728 C  -> 1k -> LFO2 3.5mm jack Tip
MCP4728 D  -> leave unconnected, or 1k -> optional clock 3.5mm jack Tip (clock lfo1|lfo2 command)
All output jack sleeves -> Pico GND
Therevox expression output plug physical Ring -> leave unconnected
```

Optional finishing supplies:

| Item | Notes |
| --- | --- |
| Heat shrink or electrical tape | Insulate jack/control solder joints |
| Small zip ties or hot glue | Strain relief for lid and jack wires |
| Knob for encoder | Included with Adafruit encoder kit, but any matching knob is fine |

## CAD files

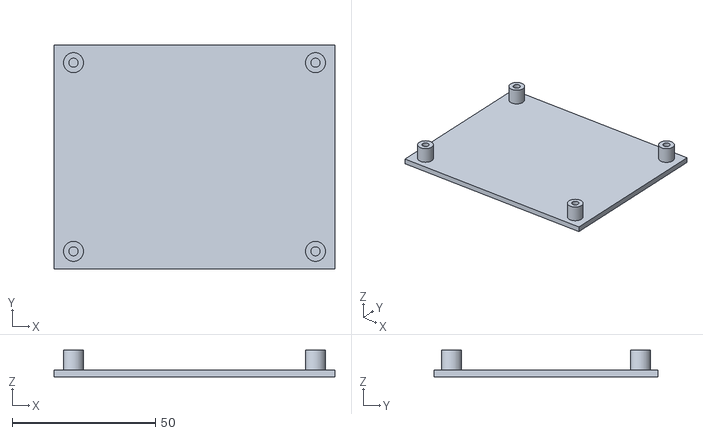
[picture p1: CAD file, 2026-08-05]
hardware/enclosure/stl/expression_controller_baseplate.stl
98.0 x 78.0 x 9.40

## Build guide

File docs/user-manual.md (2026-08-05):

# User Manual

This controller has one expression output and two dedicated LFO outputs.

```text
EXP   main 1/4 inch output for Therevox expression/CV control
LFO1  first 3.5mm patch output
LFO2  second 3.5mm patch output
```

For patch-panel ideas using these outputs with the Therevox ET-5, see
`sample-patches.md`.

The encoder edits one output at a time. Double-click the encoder to cycle the
edit target:

```text
EXP -> LFO1 -> LFO2 -> EXP
```

## Outputs

`EXP` has three modes:

| Mode | What It Does |
| --- | --- |
| `PED` | Expression pedal bends from no-bend to the selected musical interval |
| `LO` | Expression output becomes a slow LFO; the pedal controls LFO speed |
| `FM` | Expression output becomes a faster modulation source; the pedal controls speed |

`LFO1` and `LFO2` are always LFO outputs. They each have independent mode,
waveform, speed, depth, and polarity settings.

## Normal Controls

| Action | Result |
| --- | --- |
| Turn encoder with `EXP` focused in `PED` | Change the interval by one semitone |
| Turn encoder with `EXP` focused in `LO` or `FM` | Change expression-output LFO depth |
| Turn encoder with `LFO1` or `LFO2` focused | Change that LFO output speed |
| Move pedal with `EXP` focused in `LO` or `FM` | Sweep expression-output LFO speed |
| Short press with `EXP` focused in `PED` | Reset interval to unison |
| Short press with any LFO focused | Sync that LFO phase |
| Double-click | Cycle edit target: `EXP`, `LFO1`, `LFO2` |
| Hold about 2 seconds | Open or close the OLED menu |

## Main Screen

In normal expression mode:

```text
+3       TOE 1430MV
          RSP 924C
          CRV LIN
UP SAVED
```

| Text | Meaning |
| --- | --- |
| `+3` | Selected interval |
| `TOE 1430MV` | Target voltage when the pedal is toe-down |
| `RSP 924C` | Current response fit in cents across full DAC range |
| `CRV LIN` | Pedal curve |
| `UP SAVED` | Bend direction and saved/dirty state |

In expression LFO mode:

```text
LO        SPD PED
          DEP 100%
          SIN UP
LFO SAVED
```

`SPD PED` means the expression pedal controls the LFO speed. The encoder changes
depth while `EXP` is focused in `LO` or `FM`.

For a dedicated LFO output:

```text
LFO1      SPD 2.50HZ
          DEP 75%
          TRI UP
LFO1 SAVED
```

The encoder changes the shown speed while that LFO is focused.

## Menu

Hold the encoder for about 2 seconds to open the menu. Turn the encoder to
scroll, short press to edit or choose, and hold again to exit.

| Item | Applies To | Meaning |
| --- | --- | --- |
| `OUT` | All modes | Choose the edit target: `EXP`, `LFO1`, or `LFO2` |
| `MODE` | Focused output | Choose `PED`, `LO`, or `FM` for `EXP`; choose `LO` or `FM` for `LFO1`/`LFO2` |
| `WAVE` | LFO modes only | Choose the LFO waveform |
| `DEPTH` | LFO modes only | Set LFO depth from `0%` to `100%` |
| `PW` | Pulse wave only | Set pulse width from `5%` to `95%` |
| `OFS` | `LFO1`/`LFO2` | Shift the LFO center voltage `-50%` to `+50%` |
| `LINK` | `LFO2` only | Lock LFO2's rate to LFO1: `OFF`, `1:1`, `1:2`, `1:4`, `3:2`, `2:1`, `4:1` |
| `PHS` | `LFO2` when linked | Linked phase offset: `0`, `90`, `180`, or `270` degrees |
| `CLK` | All modes | Clock square on the DAC's spare channel: `OFF`, `LFO1`, `LFO2` |
| `CURVE` | `EXP` only | Set expression pedal response curve |
| `CAL` | `EXP` only | Start heel/toe pedal calibration |
| `DIR` | `EXP` in `PED` | Toggle bend direction |
| `POL` | LFO modes | Toggle LFO polarity |
| `DONE` | All modes | Close the menu |

Items only appear when they apply: `WAVE`/`DEPTH` hide while `EXP` is in normal
`PED` mode, `PW` shows only when the focused wave is pulse, `OFS` shows only for
`LFO1`/`LFO2`, `LINK`/`PHS` show only for `LFO2` (and `PHS` only while linked),
and `CURVE`/`CAL` hide while editing `LFO1` or `LFO2`.

## LFO Modes

| Setting | Choices |
| --- | --- |
| Mode | `LO`, `FM` |
| Wave | `SIN`, `TRI`, `SAWUP`, `SAWDN`, `SQR`, `PULS`, `SH`, `DRF` |
| Depth | `0%` through `100%`, in `5%` steps |
| Pulse width | `5%` through `95%` (pulse wave only) |
| Offset | `-50%` through `+50%` (`LFO1`/`LFO2` only) |
| Polarity | `UP`, `DN` |

`LO` covers slow LFO rates from about `0.05Hz` to `20Hz`.

`FM` covers faster rates from about `8Hz` to `160Hz`. The high end is useful for
rough modulation effects, but the MCP4728 is an I2C DAC, not a high-fidelity
audio DAC.

Waveform meanings:

| Wave | Shape |
| --- | --- |
| `SIN` | Smooth sine wave |
| `TRI` | Linear rise and fall |
| `SAWUP` | Rising ramp, then instant reset low |
| `SAWDN` | Falling ramp, then instant reset high |
| `SQR` | 50% square wave |
| `PULS` | Pulse wave, width set by `PW` (default 25%) |
| `SH` | Sample+hold: a new random level each cycle |
| `DRF` | Drift: smooth glide between random levels |

Depth is centered around the middle voltage. At `100%`, the LFO uses the full
`0-3.3V` range. At `75%`, the peaks are 75% as far above and below the midpoint.
At `0%`, the output sits flat at the midpoint — combine depth `0` with `OFS` to
use a dedicated LFO jack as a fixed CV source.

`OFS` shifts the whole waveform up or down after depth is applied, clamped to
the `0-3.3V` rails.

## Linking LFO2 To LFO1

`LINK` locks LFO2's rate to a ratio of LFO1's, computed from LFO1's phase so the
pair can never drift apart. `1:2` runs LFO2 at half LFO1's speed; `3:2` gives a
polyrhythm; `1:1` with `PHS 90` gives a quadrature pair for stereo-style
modulation.

While linked, LFO2's own speed setting is ignored, and turning the encoder with
`LFO2` focused steps the phase offset instead of the rate.

## Clock Output

`CLK` drives the MCP4728's spare fourth channel (`D`) with a full-swing
`0/3.3V` square at LFO1's or LFO2's rate, ignoring that LFO's wave, depth, and
offset. Wire `D` through a 1k resistor to a spare 3.5mm jack to clock
external gear in time with your modulation.

## Sync And Tap Tempo

Short-pressing the encoder while an LFO is focused syncs the selected LFO phase.
That means the waveform restarts at the beginning of its cycle.

Examples:

| Wave | What Sync Does |
| --- | --- |
| `SAWUP` | Jump to low and start rising |
| `SAWDN` | Jump to high and start falling |
| `SQR` | Restart at the first half of the square wave |
| `SIN` | Restart at the midpoint and rise |

Sync does not change depth, waveform, polarity, or output focus.

Two short presses in a row also **tap tempo**: if the gap between presses is
between about half a second and five seconds, the focused LFO's rate is set to
the tapped interval (the OLED shows `TAP` instead of `SYNC`). Faster tempos than
that collide with the double-click gesture — use serial `tap` or `rate <hz>`
for those.

Serial `sync all` restarts every LFO phase together — useful to re-align a
patch after the free-running LFOs have wandered apart.

## Pedal Calibration

Calibration teaches the Pico the heel and toe raw values from your expression
pedal.

1. Focus `EXP`.
2. Hold the encoder for about 2 seconds to open the menu.
3. Turn to `CAL`.
4. Short press. The OLED says `HEEL`.
5. Put the pedal fully heel-down.
6. Short press. The OLED says `TOE`.
7. Put the pedal fully toe-down.
8. Short press again. The OLED says `SAVED`.

If the pedal moves backward after calibration, use Serial Monitor:

```text
invert on
save
```

## Direction And Polarity

For `EXP` in `PED` mode:

```text
UP    heel/no-bend is 0V; toe bends upward
DOWN  heel/no-bend is 3.3V; toe bends downward
```

For LFO modes:

```text
UP    normal waveform
DN    inverted waveform
```

## Autosave

Settings autosave about 3 seconds after the last change. The firmware also saves
immediately after menu edits and calibration.

Some Pico board cores do not provide EEPROM persistence. If Serial Monitor says
settings were kept in RAM only, keep a copy of your important `response`, `map`,
and tuning commands.

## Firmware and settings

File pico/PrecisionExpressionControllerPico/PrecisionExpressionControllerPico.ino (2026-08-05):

// Therevox Expression Controller - Raspberry Pi Pico H prototype
//
// Hardware target:
//   Raspberry Pi Pico H
//   MCP4728 quad DAC breakout, I2C address 0x60
//   Adafruit 0.91" 128x32 SSD1306 OLED, I2C address 0x3C
//   Adafruit rotary encoder + push switch
//   Two 1/4" TRS jacks: expression pedal input and Therevox expression/CV output
//   Two 3.5mm TS jacks: dedicated Therevox patch-panel LFO outputs
//
// Exact Pico H wiring:
//   Expression input TRS Ring   -> Pico pin labeled 3V3(OUT), physical pin 36
//   Expression input TRS Sleeve -> Pico pin labeled GND, physical pin 38
//   Expression input TRS Tip    -> 1k resistor -> Pico pin labeled GP26/ADC0, physical pin 31
//   GP26/ADC0 side of 1k       -> 100nF capacitor -> GND
//
//   MCP4728 V                   -> Pico pin labeled 3V3(OUT), physical pin 36
//   MCP4728 S                   -> Pico pin labeled GND, physical pin 38
//                                  The DAC board ground pin is printed "S".
//   MCP4728 DA                  -> Pico pin labeled GP4, physical pin 6
//   MCP4728 CL                  -> Pico pin labeled GP5, physical pin 7
//   MCP4728 L                   -> GND (required; outputs freeze if LDAC floats high)
//   MCP4728 R                   -> not connected
//   MCP4728 A                   -> 1k resistor -> output plug physical Tip
//   Output plug physical Ring   -> not connected for active external CV
//   Output TRS Sleeve           -> GND
//   MCP4728 B                   -> 1k resistor -> LFO 1 3.5mm jack Tip
//   MCP4728 C                   -> 1k resistor -> LFO 2 3.5mm jack Tip
//   MCP4728 D                   -> 1k resistor -> optional clock 3.5mm jack Tip
//   LFO 1/2/clock jack Sleeve   -> GND
//
//   The firmware uses MCP4728 multi-write commands (UDAC=0), which set
//   VREF=VDD and gain=1 on every update and latch outputs regardless of the
//   LDAC pin state. Grounding LDAC is still recommended.
//
//   OLED red/VCC                -> Pico pin labeled 3V3(OUT), physical pin 36
//   OLED black/GND              -> Pico pin labeled GND, physical pin 38
//   OLED blue/SDA               -> Pico pin labeled GP4, physical pin 6
//   OLED yellow/SCL             -> Pico pin labeled GP5, physical pin 7
//
//   Encoder C/common            -> GND
//   Encoder A/CLK               -> Pico pin labeled GP14, physical pin 19
//   Encoder B/DT                -> Pico pin labeled GP15, physical pin 20
//   Encoder switch lug          -> Pico pin labeled GP13, physical pin 17
//   Encoder other switch lug    -> GND
//
// Control model:
//   PED mode: expression pedal controls calibrated interval bend.
//   UP mode:   heel/no-bend 0.000 V, top interval +6 / 9 semitones.
//   DOWN mode: heel/no-bend 3.300 V, bottom interval -6 / -9 semitones.
//   LO mode: slow unipolar LFO, 0.05-20 Hz.
//   FM mode: faster unipolar LFO, 8-160 Hz.
//   In LO/FM, the expression pedal sweeps LFO speed and the encoder sets depth.
//   LFO 1 and LFO 2 are independent dedicated patch-panel CV outputs.
//   LFO 2 can link to LFO 1 at a rate ratio with a quarter-cycle phase offset.
//   DAC D can emit a full-swing clock square derived from LFO 1 or LFO 2.
//   Double-click the encoder to cycle the active edit target: EXP, LFO1, LFO2.
//   Repeated single presses on a focused LFO tap-tempo its rate.
//
// Tune/calibrate the Therevox with the controller connected and the pedal at heel.

#include <Arduino.h>
#include <Wire.h>
#include <math.h>
#include <stddef.h>
#include <stdint.h>
#include <stdio.h>
#include <stdlib.h>
#include <string.h>

#if defined(__has_include)
#if __has_include(<EEPROM.h>)
#include <EEPROM.h>
#define EXPCTRL_PICO_HAS_EEPROM 1
#endif
#endif

#ifndef EXPCTRL_PICO_HAS_EEPROM
#define EXPCTRL_PICO_HAS_EEPROM 0
#endif

#if EXPCTRL_PICO_HAS_EEPROM && !defined(ARDUINO_ARCH_MBED)
#define EXPCTRL_PICO_USE_EEPROM 1
#else
#define EXPCTRL_PICO_USE_EEPROM 0
#endif

#include "PicoFirmwareCore.h"

using namespace expctrl;

namespace {

constexpr uint32_t SERIAL_BAUD = 115200;
constexpr uint8_t PEDAL_PIN = A0;          // Pico GP26/ADC0, physical pin 31.
constexpr uint8_t I2C_SDA_PIN = 4;         // Pico GP4, physical pin 6.
constexpr uint8_t I2C_SCL_PIN = 5;         // Pico GP5, physical pin 7.
constexpr uint8_t ENCODER_SWITCH_PIN = 13; // Pico GP13, physical pin 17.
constexpr uint8_t ENCODER_A_PIN = 14;      // Pico GP14, physical pin 19.
constexpr uint8_t ENCODER_B_PIN = 15;      // Pico GP15, physical pin 20.
constexpr uint8_t MCP4728_ADDRESS = 0x60;
constexpr uint8_t SSD1306_ADDRESS = 0x3C;
constexpr uint8_t LFO_OUT_COUNT = 2;
constexpr uint8_t DAC_CHANNEL_COUNT = 4;
constexpr uint8_t ADC_BITS = 12;
constexpr uint16_t ADC_MAX = (1u << ADC_BITS) - 1u;
constexpr uint8_t PEDAL_OVERSAMPLES = 8;
constexpr uint32_t CONTROL_PERIOD_US = 1000;
constexpr uint32_t MONITOR_MS = 500;
constexpr uint32_t DISPLAY_MS = 500;
constexpr uint32_t HEARTBEAT_MS = 1000;
constexpr uint32_t BUTTON_DEBOUNCE_MS = 30;
constexpr uint32_t BUTTON_DOUBLE_CLICK_MS = 400;
constexpr uint32_t MENU_LONG_PRESS_MS = 2000;
constexpr uint32_t CAL_MESSAGE_MS = 1500;
constexpr uint32_t CAL_PROMPT_MS = 60UL * 1000UL;
constexpr bool IDLE_SLEEP_ENABLED = false;
constexpr uint32_t IDLE_SLEEP_MS = 60UL * 60UL * 1000UL;
constexpr uint32_t SETTINGS_AUTOSAVE_MS = 3000;
constexpr uint32_t DAC_PEDAL_WRITE_MIN_INTERVAL_US = 5000;
constexpr uint32_t DAC_LFO_WRITE_MIN_INTERVAL_US = 1000;
constexpr uint16_t DAC_CODE_DEADBAND = 2;
constexpr uint16_t PEDAL_ACTIVITY_RAW_DELTA = 8;
constexpr uint16_t MIN_CAL_SPAN_RAW = 128;
constexpr float PEDAL_SNAP_LOW = 0.005f;
constexpr float PEDAL_SNAP_HIGH = 0.995f;
constexpr float PEDAL_DEADBAND = 0.0005f;
constexpr uint8_t DISPLAY_WIDTH = 128;
constexpr uint8_t DISPLAY_HEIGHT = 32;
constexpr uint16_t DISPLAY_BUFFER_SIZE = DISPLAY_WIDTH * DISPLAY_HEIGHT / 8;
constexpr uint32_t SETTINGS_MAGIC = 0x5049434FUL; // PICO
constexpr uint16_t SETTINGS_VERSION = 12;
constexpr uint16_t SETTINGS_VERSION_PREVIOUS = 11;
constexpr uint32_t TAP_MIN_MS = 450;
constexpr uint32_t TAP_MAX_MS = 5000;
constexpr uint16_t DEFAULT_RANGE_MV = static_cast<uint16_t>(kDefaultUnipolarOctaveMicrovolts / 1000L);
constexpr uint16_t MAX_OUTPUT_MV = static_cast<uint16_t>(kPicoDacFullScaleMicrovolts / 1000L);
constexpr uint16_t MAX_OCTAVE_SCALE_MV = MAX_OUTPUT_MV;
constexpr uint16_t DEFAULT_TUNE_STEP_MV = 10;
constexpr uint16_t MAX_TUNE_STEP_MV = 250;

enum OutputFocus : uint8_t {
  OUTPUT_FOCUS_EXP = 0,
  OUTPUT_FOCUS_LFO1 = 1,
  OUTPUT_FOCUS_LFO2 = 2,
  OUTPUT_FOCUS_COUNT = 3,
};

struct PicoSettings {
  uint32_t magic;
  uint16_t version;
  uint16_t size;
  uint16_t heelRaw;
  uint16_t toeRaw;
  int8_t semitones;
  uint8_t invert;
  uint8_t monitorEnabled;
  uint8_t bendDirection;
  uint8_t curveMode;
  uint8_t outputMode;
  uint8_t lfoWave;
  uint8_t lfoLoRate;
  uint8_t lfoFmRate;
  uint8_t lfoDepthPercent;
  uint8_t outputFocus;
  uint8_t lfoOutMode[LFO_OUT_COUNT];
  uint8_t lfoOutWave[LFO_OUT_COUNT];
  uint8_t lfoOutLoRate[LFO_OUT_COUNT];
  uint8_t lfoOutFmRate[LFO_OUT_COUNT];
  uint8_t lfoOutDepthPercent[LFO_OUT_COUNT];
  uint8_t lfoOutPolarity[LFO_OUT_COUNT];
  uint8_t lfoPulseWidth;
  uint8_t lfoOutPulseWidth[LFO_OUT_COUNT];
  int8_t lfoOutOffsetPercent[LFO_OUT_COUNT];
  uint8_t lfo2Link;
  uint8_t lfo2PhaseOffset;
  uint8_t clockSource;
  uint16_t rangeMv;
  uint16_t responseCents;
  uint16_t toeMapMv[kPicoSemitoneMapCount];
  uint32_t checksum;
};

// Exact on-flash layout of settings version 11, kept so an upgrade preserves
// calibration and the hand-tuned toe map instead of wiping them.
struct PicoSettingsV11 {
  uint32_t magic;
  uint16_t version;
  uint16_t size;
  uint16_t heelRaw;
  uint16_t toeRaw;
  int8_t semitones;
  uint8_t invert;
  uint8_t monitorEnabled;
  uint8_t bendDirection;
  uint8_t curveMode;
  uint8_t outputMode;
  uint8_t lfoWave;
  uint8_t lfoLoRate;
  uint8_t lfoFmRate;
  uint8_t lfoDepthPercent;
  uint8_t outputFocus;
  uint8_t lfoOutMode[LFO_OUT_COUNT];
  uint8_t lfoOutWave[LFO_OUT_COUNT];
  uint8_t lfoOutLoRate[LFO_OUT_COUNT];
  uint8_t lfoOutFmRate[LFO_OUT_COUNT];
  uint8_t lfoOutDepthPercent[LFO_OUT_COUNT];
  uint8_t lfoOutPolarity[LFO_OUT_COUNT];
  uint16_t rangeMv;
  uint16_t responseCents;
  uint16_t toeMapMv[kPicoSemitoneMapCount];
  uint32_t checksum;
};

enum CalibrationState {
  CAL_IDLE,
  CAL_WAIT_HEEL,
  CAL_WAIT_TOE,
};

enum MenuItem : uint8_t {
  MENU_OUT = 0,
  MENU_MODE = 1,
  MENU_WAVE = 2,
  MENU_DEPTH = 3,
  MENU_PW = 4,
  MENU_OFS = 5,
  MENU_LINK = 6,
  MENU_PHS = 7,
  MENU_CLK = 8,
  MENU_CURVE = 9,
  MENU_CAL = 10,
  MENU_DIR = 11,
  MENU_DONE = 12,
  MENU_COUNT = 13,
};

enum MenuEditField : uint8_t {
  MENU_EDIT_NONE = 0,
  MENU_EDIT_OUT,
  MENU_EDIT_MODE,
  MENU_EDIT_WAVE,
  MENU_EDIT_DEPTH,
  MENU_EDIT_PW,
  MENU_EDIT_OFS,
  MENU_EDIT_LINK,
  MENU_EDIT_PHS,
  MENU_EDIT_CLK,
  MENU_EDIT_CURVE,
};

uint16_t microvoltsToMillivolts(int32_t microvolts) {
  return static_cast<uint16_t>(
      clampValue<int32_t>((microvolts + 500L) / 1000L, 0, MAX_OUTPUT_MV));
}

uint16_t linearToeMillivoltsForSemitone(int semitones, uint16_t rangeMv) {
  return microvoltsToMillivolts(
      computePicoUnipolarToeMicrovolts(semitones,
                                       static_cast<int32_t>(rangeMv) * 1000L));
}

void fillLinearToeMap(PicoSettings& value) {
  for (int semitone = kPicoMinSemitones; semitone <= kPicoMaxSemitones; ++semitone) {
    value.toeMapMv[picoSemitoneMapIndex(semitone)] =
        linearToeMillivoltsForSemitone(semitone, value.rangeMv);
  }
  value.toeMapMv[picoSemitoneMapIndex(0)] = 0;
}

uint16_t responseToeMillivoltsForSemitone(int semitones, uint16_t responseCents) {
  return microvoltsToMillivolts(
      computePicoResponseToeMicrovolts(semitones, responseCents));
}

void fillResponseToeMap(PicoSettings& value) {
  for (int semitone = kPicoMinSemitones; semitone <= kPicoMaxSemitones; ++semitone) {
    value.toeMapMv[picoSemitoneMapIndex(semitone)] =
        responseToeMillivoltsForSemitone(semitone, value.responseCents);
  }
  value.toeMapMv[picoSemitoneMapIndex(0)] = 0;
}

void fillToeMapFromCurrentFit(PicoSettings& value) {
  if (value.responseCents > 0) {
    fillResponseToeMap(value);
  } else {
    fillLinearToeMap(value);
  }
}

bool toeMapValid(const PicoSettings& value) {
  for (uint8_t i = 0; i < kPicoSemitoneMapCount; ++i) {
    if (value.toeMapMv[i] > MAX_OUTPUT_MV) {
      return false;
    }
  }
  return true;
}

PicoSettings settings;
PedalProcessor pedalProcessor;
PedalState pedalState;
CalibrationState calState = CAL_IDLE;

uint16_t currentRaw = 0;
uint16_t lastActivityRaw = 0;
int32_t currentOutputMicrovolts = 0;
int32_t lfoOutOutputMicrovolts[LFO_OUT_COUNT] = {0, 0};
uint16_t currentDacCode = 0;
uint16_t lfoOutDacCode[LFO_OUT_COUNT] = {0, 0};
int lastWrittenDacCodes[DAC_CHANNEL_COUNT] = {-1, -1, -1, -1};
bool dacReady = false;
bool displayReady = false;
bool sleeping = false;
bool settingsDirty = false;
bool tuneMode = false;
bool cvOverrideEnabled = false;
uint16_t cvOverrideMv = 0;
uint16_t tuneStepMv = DEFAULT_TUNE_STEP_MV;

uint32_t lastControlUs = 0;
uint32_t lastDacWriteUs = 0;
uint32_t lastMonitorMs = 0;
uint32_t lastDisplayMs = 0;
uint32_t lastHeartbeatMs = 0;
uint32_t lastActivityMs = 0;
uint32_t lastSettingsChangeMs = 0;
uint32_t displayMessageUntilMs = 0;

uint8_t displayBuffer[DISPLAY_BUFFER_SIZE];
char displayMessageTop[16] = "";
char displayMessageBottom[24] = "";
char serialLine[96];
size_t serialLineLength = 0;

bool displayForceUpdate = true;
bool lastRenderedMessage = false;
int lastRenderedCalState = -1;
int lastRenderedSemitones = 999;
bool lastRenderedDacReady = false;
bool lastRenderedSettingsDirty = false;
bool lastRenderedTuneMode = false;
bool lastRenderedCvOverrideEnabled = false;
uint16_t lastRenderedCvOverrideMv = 0xffff;
bool lastRenderedMenuActive = false;
uint8_t lastRenderedMenuIndex = 0xff;
uint8_t lastRenderedMenuEditField = 0xff;
uint8_t lastRenderedMenuEditValue = 0xff;
uint8_t lastRenderedCurveMode = 0xff;
uint8_t lastRenderedBendDirection = 0xff;
uint8_t lastRenderedOutputFocus = 0xff;
uint8_t lastRenderedOutputMode = 0xff;
uint8_t lastRenderedLfoWave = 0xff;
uint8_t lastRenderedLfoLoRate = 0xff;
uint8_t lastRenderedLfoFmRate = 0xff;
uint8_t lastRenderedLfoDepthPercent = 0xff;
uint8_t lastRenderedLfoOutMode[LFO_OUT_COUNT] = {0xff, 0xff};
uint8_t lastRenderedLfoOutWave[LFO_OUT_COUNT] = {0xff, 0xff};
uint8_t lastRenderedLfoOutLoRate[LFO_OUT_COUNT] = {0xff, 0xff};
uint8_t lastRenderedLfoOutFmRate[LFO_OUT_COUNT] = {0xff, 0xff};
uint8_t lastRenderedLfoOutDepthPercent[LFO_OUT_COUNT] = {0xff, 0xff};
uint8_t lastRenderedLfoOutPolarity[LFO_OUT_COUNT] = {0xff, 0xff};
uint8_t lastRenderedLfoOutPulseWidth[LFO_OUT_COUNT] = {0xff, 0xff};
int8_t lastRenderedLfoOutOffsetPercent[LFO_OUT_COUNT] = {-128, -128};
uint8_t lastRenderedLfoPulseWidth = 0xff;
uint8_t lastRenderedLfo2Link = 0xff;
uint8_t lastRenderedLfo2PhaseOffset = 0xff;
uint8_t lastRenderedClockSource = 0xff;

bool menuActive = false;
uint8_t menuIndex = MENU_OUT;
uint8_t menuEditField = MENU_EDIT_NONE;
uint8_t menuEditValue = 0;
float lfoPhase = 0.0f;
uint32_t lfoCycle = 0;
uint32_t lastLfoUs = 0;
float lfoOutPhase[LFO_OUT_COUNT] = {0.0f, 0.0f};
uint32_t lfoOutCycle[LFO_OUT_COUNT] = {0, 0};
uint32_t lastLfoOutUs[LFO_OUT_COUNT] = {0, 0};
uint16_t clockDacCode = 0;
uint32_t lastTapMs = 0;
uint8_t lastTapFocus = 0xff;

// Fixed hash seeds so each output gets its own S+H/drift random sequence.
constexpr uint32_t LFO_SEED_EXP = 0xE0u;
constexpr uint32_t LFO_SEED_OUT[LFO_OUT_COUNT] = {0xA1u, 0xB2u};

volatile uint8_t lastEncoderState = 0;
volatile int8_t encoderTransitionCount = 0;
volatile int8_t encoderPendingSteps = 0;
volatile uint32_t encoderTransitionEvents = 0;
bool encoderDebug = false;
bool buttonDebug = false;

bool lastButtonRawPressed = false;
bool stableButtonPressed = false;
bool buttonReleasedSinceBoot = false;
uint32_t lastButtonChangeMs = 0;
uint32_t buttonPressStartedMs = 0;
bool buttonLongHandled = false;
bool buttonIgnoreRelease = false;
bool pendingShortPress = false;
uint32_t pendingShortPressMs = 0;

uint32_t fnv1a(const uint8_t* data, size_t length) {
  uint32_t hash = 2166136261UL;
  for (size_t i = 0; i < length; ++i) {
    hash ^= data[i];
    hash *= 16777619UL;
  }
  return hash;
}

uint32_t settingsChecksum(const PicoSettings& value) {
  return fnv1a(reinterpret_cast<const uint8_t*>(&value), offsetof(PicoSettings, checksum));
}

void finalizeSettings(PicoSettings& value) {
  value.magic = SETTINGS_MAGIC;
  value.version = SETTINGS_VERSION;
  value.size = sizeof(PicoSettings);
  value.checksum = settingsChecksum(value);
}

bool settingsValid(const PicoSettings& value) {
  if (!(value.magic == SETTINGS_MAGIC &&
        value.version == SETTINGS_VERSION &&
        value.size == sizeof(PicoSettings) &&
        value.checksum == settingsChecksum(value) &&
        value.heelRaw <= ADC_MAX &&
        value.toeRaw <= ADC_MAX &&
        value.rangeMv <= MAX_OCTAVE_SCALE_MV &&
        value.responseCents <= 6000 &&
        value.bendDirection <= static_cast<uint8_t>(kPicoBendDown) &&
        value.curveMode < kPicoCurveCount &&
        value.outputMode < kPicoOutputModeCount &&
        value.lfoWave < kPicoLfoWaveCount &&
        value.lfoLoRate <= kPicoLfoLoRateSteps &&
        value.lfoFmRate <= kPicoLfoFmRateSteps &&
        value.lfoDepthPercent >= kPicoLfoMinDepthPercent &&
        value.lfoDepthPercent <= kPicoLfoMaxDepthPercent &&
        ((value.lfoDepthPercent - kPicoLfoMinDepthPercent) % kPicoLfoDepthStepPercent == 0) &&
        value.outputFocus < OUTPUT_FOCUS_COUNT &&
        toeMapValid(value) &&
        value.semitones >= kPicoMinSemitones &&
        value.semitones <= kPicoMaxSemitones &&
        ((value.bendDirection == static_cast<uint8_t>(kPicoBendDown) && value.semitones <= 0) ||
         (value.bendDirection == static_cast<uint8_t>(kPicoBendUp) && value.semitones >= 0)))) {
    return false;
  }

  for (uint8_t i = 0; i < LFO_OUT_COUNT; ++i) {
    if (value.lfoOutMode[i] != kPicoOutputLfoLo &&
        value.lfoOutMode[i] != kPicoOutputLfoFm) {
      return false;
    }
    if (value.lfoOutWave[i] >= kPicoLfoWaveCount ||
        value.lfoOutLoRate[i] > kPicoLfoLoRateSteps ||
        value.lfoOutFmRate[i] > kPicoLfoFmRateSteps ||
        value.lfoOutDepthPercent[i] < kPicoLfoMinDepthPercent ||
        value.lfoOutDepthPercent[i] > kPicoLfoMaxDepthPercent ||
        ((value.lfoOutDepthPercent[i] - kPicoLfoMinDepthPercent) %
             kPicoLfoDepthStepPercent !=
         0) ||
        value.lfoOutPolarity[i] > 1) {
      return false;
    }
    if (value.lfoOutPulseWidth[i] < kPicoLfoMinPulseWidthPercent ||
        value.lfoOutPulseWidth[i] > kPicoLfoMaxPulseWidthPercent ||
        value.lfoOutOffsetPercent[i] < kPicoLfoMinOffsetPercent ||
        value.lfoOutOffsetPercent[i] > kPicoLfoMaxOffsetPercent) {
      return false;
    }
  }

  return value.lfoPulseWidth >= kPicoLfoMinPulseWidthPercent &&
         value.lfoPulseWidth <= kPicoLfoMaxPulseWidthPercent &&
         value.lfo2Link < kPicoLfoLinkCount &&
         value.lfo2PhaseOffset < kPicoLfoPhaseOffsetCount &&
         value.clockSource < kPicoClockSourceCount;
}

uint32_t settingsChecksumV11(const PicoSettingsV11& value) {
  return fnv1a(reinterpret_cast<const uint8_t*>(&value), offsetof(PicoSettingsV11, checksum));
}

bool settingsValidV11(const PicoSettingsV11& value) {
  return value.magic == SETTINGS_MAGIC &&
         value.version == SETTINGS_VERSION_PREVIOUS &&
         value.size == sizeof(PicoSettingsV11) &&
         value.checksum == settingsChecksumV11(value) &&
         value.heelRaw <= ADC_MAX &&
         value.toeRaw <= ADC_MAX &&
         value.rangeMv <= MAX_OCTAVE_SCALE_MV &&
         value.responseCents <= 6000 &&
         value.semitones >= kPicoMinSemitones &&
         value.semitones <= kPicoMaxSemitones;
}

PicoSettings makeDefaultPicoSettings() {
  PicoSettings value;
  memset(&value, 0, sizeof(value));
  value.heelRaw = 0;
  value.toeRaw = ADC_MAX;
  value.semitones = kPicoMaxSemitones;
  value.invert = 0;
  value.monitorEnabled = 1;
  value.bendDirection = static_cast<uint8_t>(kPicoBendUp);
  value.curveMode = kPicoCurveLinear;
  value.outputMode = kPicoOutputPedal;
  value.lfoWave = kPicoLfoSine;
  value.lfoLoRate = kPicoLfoLoRateSteps;
  value.lfoFmRate = kPicoLfoFmRateSteps;
  value.lfoDepthPercent = kPicoLfoMaxDepthPercent;
  value.outputFocus = OUTPUT_FOCUS_EXP;
  for (uint8_t i = 0; i < LFO_OUT_COUNT; ++i) {
    value.lfoOutMode[i] = kPicoOutputLfoLo;
    value.lfoOutWave[i] = i == 0 ? kPicoLfoSine : kPicoLfoTriangle;
    value.lfoOutLoRate[i] = kPicoDefaultLfoLoRate;
    value.lfoOutFmRate[i] = kPicoDefaultLfoFmRate;
    value.lfoOutDepthPercent[i] = kPicoLfoMaxDepthPercent;
    value.lfoOutPolarity[i] = static_cast<uint8_t>(kPicoBendUp);
    value.lfoOutPulseWidth[i] = kPicoDefaultLfoPulseWidthPercent;
    value.lfoOutOffsetPercent[i] = 0;
  }
  value.lfoPulseWidth = kPicoDefaultLfoPulseWidthPercent;
  value.lfo2Link = kPicoLfoLinkOff;
  value.lfo2PhaseOffset = kPicoLfoPhase0;
  value.clockSource = kPicoClockOff;
  value.rangeMv = DEFAULT_RANGE_MV;
  value.responseCents = kDefaultFullScaleResponseCents;
  fillToeMapFromCurrentFit(value);
  finalizeSettings(value);
  return value;
}

void configureProcessor() {
  PedalCalibration calibration;
  calibration.heelRaw = settings.heelRaw;
  calibration.toeRaw = settings.toeRaw;
  calibration.invert = settings.invert != 0;
  calibration.snapLow = PEDAL_SNAP_LOW;
  calibration.snapHigh = PEDAL_SNAP_HIGH;
  calibration.deadband = PEDAL_DEADBAND;

  PedalFilterSettings filterSettings;
  filterSettings.enabled = true;
  filterSettings.minCutoffHz = 3.5f;
  filterSettings.beta = 0.12f;
  filterSettings.derivativeCutoffHz = 1.0f;

  pedalProcessor.configure(calibration, filterSettings, settings.curveMode);
  pedalProcessor.reset();
}

void markSettingsDirty() {
  settingsDirty = true;
  lastSettingsChangeMs = millis();
  finalizeSettings(settings);
}
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
void loop() {
  uint32_t nowMs = millis();
  uint32_t nowUs = micros();

  pollSerial();
  pollEncoder();
  pollEncoderButton();
  pollPendingShortPress();

  if (static_cast<uint32_t>(nowUs - lastControlUs) >= CONTROL_PERIOD_US) {
    lastControlUs += CONTROL_PERIOD_US;
    updateControl();
  }

  if (!sleeping && settings.monitorEnabled && nowMs - lastMonitorMs >= MONITOR_MS) {
    lastMonitorMs = nowMs;
    printMonitor();
  }

  if (!sleeping && nowMs - lastDisplayMs >= DISPLAY_MS) {
    lastDisplayMs = nowMs;
    renderDisplay();
  }

  if (IDLE_SLEEP_ENABLED &&
      !sleeping && calState == CAL_IDLE && !tuneMode && !cvOverrideEnabled &&
      nowMs - lastActivityMs >= IDLE_SLEEP_MS) {
    enterSleep("IDLE");
  }

  if (!sleeping && calState == CAL_IDLE && settingsDirty &&
      nowMs - lastSettingsChangeMs >= SETTINGS_AUTOSAVE_MS) {
    saveSettings();
  }

  if (nowMs - lastHeartbeatMs >= HEARTBEAT_MS) {
    lastHeartbeatMs = nowMs;
    digitalWrite(LED_BUILTIN, !digitalRead(LED_BUILTIN));
  }
}

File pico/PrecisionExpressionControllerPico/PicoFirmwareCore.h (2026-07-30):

#pragma once

#include <math.h>
#include <stdint.h>

namespace expctrl {

template <typename T>
constexpr T clampValue(T value, T low, T high) {
  return value < low ? low : (value > high ? high : value);
}

constexpr int8_t kPicoMinSemitones = -9;
constexpr int8_t kPicoMaxSemitones = 9;
constexpr uint8_t kPicoSemitoneMapCount =
    static_cast<uint8_t>(kPicoMaxSemitones - kPicoMinSemitones + 1);
constexpr int32_t kPicoDacFullScaleMicrovolts = 3300000L;
constexpr uint16_t kMcp4728MaxCode = 4095;
constexpr int32_t kDefaultCenterMicrovolts = 1500000L;
constexpr int32_t kDefaultOctaveMicrovolts = 1500000L;
constexpr int32_t kDefaultUnipolarOctaveMicrovolts = kPicoDacFullScaleMicrovolts;
constexpr uint16_t kDefaultFullScaleResponseCents = 924;
constexpr uint8_t kPicoLfoLoRateSteps = 96;
constexpr uint8_t kPicoLfoFmRateSteps = 60;
constexpr uint8_t kPicoDefaultLfoLoRate = 48;
constexpr uint8_t kPicoDefaultLfoFmRate = 28;
constexpr float kPicoLfoLoMinHz = 0.05f;
constexpr float kPicoLfoLoMaxHz = 20.0f;
constexpr float kPicoLfoFmMinHz = 8.0f;
constexpr float kPicoLfoFmMaxHz = 160.0f;
constexpr uint8_t kPicoLfoMinDepthPercent = 0;
constexpr uint8_t kPicoLfoMaxDepthPercent = 100;
constexpr uint8_t kPicoLfoDepthStepPercent = 5;
constexpr uint8_t kPicoLfoDepthStepCount =
    ((kPicoLfoMaxDepthPercent - kPicoLfoMinDepthPercent) / kPicoLfoDepthStepPercent) + 1;
constexpr int8_t kPicoLfoMinOffsetPercent = -50;
constexpr int8_t kPicoLfoMaxOffsetPercent = 50;
constexpr uint8_t kPicoLfoOffsetStepPercent = 5;
constexpr uint8_t kPicoLfoOffsetStepCount =
    ((kPicoLfoMaxOffsetPercent - kPicoLfoMinOffsetPercent) / kPicoLfoOffsetStepPercent) + 1;
constexpr uint8_t kPicoLfoMinPulseWidthPercent = 5;
constexpr uint8_t kPicoLfoMaxPulseWidthPercent = 95;
constexpr uint8_t kPicoLfoPulseWidthStepPercent = 5;
constexpr uint8_t kPicoLfoPulseWidthStepCount =
    ((kPicoLfoMaxPulseWidthPercent - kPicoLfoMinPulseWidthPercent) /
     kPicoLfoPulseWidthStepPercent) + 1;
constexpr uint8_t kPicoDefaultLfoPulseWidthPercent = 25;

enum PicoBendDirection : uint8_t {
  kPicoBendUp = 0,
  kPicoBendDown = 1,
};

enum PicoOutputMode : uint8_t {
  kPicoOutputPedal = 0,
  kPicoOutputLfoLo = 1,
  kPicoOutputLfoFm = 2,
  kPicoOutputModeCount = 3,
};

enum PicoLfoWave : uint8_t {
  kPicoLfoSine = 0,
  kPicoLfoTriangle = 1,
  kPicoLfoSawUp = 2,
  kPicoLfoSawDown = 3,
  kPicoLfoSquare = 4,
  kPicoLfoPulse = 5,
  kPicoLfoSampleHold = 6,
  kPicoLfoDrift = 7,
  kPicoLfoWaveCount = 8,
};

enum PicoLfoLink : uint8_t {
  kPicoLfoLinkOff = 0,
  kPicoLfoLink1to1 = 1,
  kPicoLfoLink1to2 = 2,
  kPicoLfoLink1to4 = 3,
  kPicoLfoLink3to2 = 4,
  kPicoLfoLink2to1 = 5,
  kPicoLfoLink4to1 = 6,
  kPicoLfoLinkCount = 7,
};

enum PicoLfoPhaseOffset : uint8_t {
  kPicoLfoPhase0 = 0,
  kPicoLfoPhase90 = 1,
  kPicoLfoPhase180 = 2,
  kPicoLfoPhase270 = 3,
  kPicoLfoPhaseOffsetCount = 4,
};

enum PicoClockSource : uint8_t {
  kPicoClockOff = 0,
  kPicoClockLfo1 = 1,
  kPicoClockLfo2 = 2,
  kPicoClockSourceCount = 3,
};

enum PicoPedalCurve : uint8_t {
  kPicoCurveLinear = 0,
  kPicoCurveEaseOut = 1,
  kPicoCurveSquare = 2,
  kPicoCurveSmooth = 3,
  kPicoCurveCount = 4,
};

inline uint8_t clampPicoCurveMode(int value) {
  return static_cast<uint8_t>(clampValue<int>(value, 0, kPicoCurveCount - 1));
}

inline uint8_t clampPicoOutputMode(int value) {
  return static_cast<uint8_t>(clampValue<int>(value, 0, kPicoOutputModeCount - 1));
}

inline uint8_t clampPicoLfoOutputMode(int value) {
  return clampPicoOutputMode(value) == kPicoOutputLfoFm ? kPicoOutputLfoFm
                                                       : kPicoOutputLfoLo;
}

inline uint8_t clampPicoLfoWave(int value) {
  return static_cast<uint8_t>(clampValue<int>(value, 0, kPicoLfoWaveCount - 1));
}

inline uint8_t picoLfoRateMaxStep(uint8_t outputMode) {
  return clampPicoOutputMode(outputMode) == kPicoOutputLfoFm ? kPicoLfoFmRateSteps
                                                            : kPicoLfoLoRateSteps;
}

inline uint8_t clampPicoLfoRateStep(int value, uint8_t outputMode) {
  return static_cast<uint8_t>(clampValue<int>(value, 0, picoLfoRateMaxStep(outputMode)));
}

inline uint8_t clampPicoLfoDepthPercent(int value) {
  int rounded = ((value + (kPicoLfoDepthStepPercent / 2)) / kPicoLfoDepthStepPercent) *
                kPicoLfoDepthStepPercent;
  return static_cast<uint8_t>(
      clampValue<int>(rounded, kPicoLfoMinDepthPercent, kPicoLfoMaxDepthPercent));
}

inline uint8_t picoLfoDepthIndexFromPercent(int percent) {
  uint8_t clamped = clampPicoLfoDepthPercent(percent);
  return static_cast<uint8_t>((clamped - kPicoLfoMinDepthPercent) / kPicoLfoDepthStepPercent);
}

inline uint8_t picoLfoDepthPercentFromIndex(int index) {
  return clampPicoLfoDepthPercent(
      kPicoLfoMinDepthPercent + clampValue<int>(index, 0, kPicoLfoDepthStepCount - 1) *
                                    kPicoLfoDepthStepPercent);
}

inline int8_t clampPicoLfoOffsetPercent(int value) {
  int step = static_cast<int>(kPicoLfoOffsetStepPercent);
  int rounded = ((value >= 0 ? value + step / 2 : value - step / 2) / step) * step;
  return static_cast<int8_t>(
      clampValue<int>(rounded, kPicoLfoMinOffsetPercent, kPicoLfoMaxOffsetPercent));
}

inline uint8_t picoLfoOffsetIndexFromPercent(int percent) {
  int8_t clamped = clampPicoLfoOffsetPercent(percent);
  return static_cast<uint8_t>((clamped - kPicoLfoMinOffsetPercent) / kPicoLfoOffsetStepPercent);
}

inline int8_t picoLfoOffsetPercentFromIndex(int index) {
  return clampPicoLfoOffsetPercent(
      kPicoLfoMinOffsetPercent + clampValue<int>(index, 0, kPicoLfoOffsetStepCount - 1) *
                                     kPicoLfoOffsetStepPercent);
}

inline uint8_t clampPicoLfoPulseWidth(int value) {
  int step = static_cast<int>(kPicoLfoPulseWidthStepPercent);
  int rounded = ((value + step / 2) / step) * step;
  return static_cast<uint8_t>(clampValue<int>(rounded,
                                              kPicoLfoMinPulseWidthPercent,
                                              kPicoLfoMaxPulseWidthPercent));
}

inline uint8_t picoLfoPulseWidthIndexFromPercent(int percent) {
  uint8_t clamped = clampPicoLfoPulseWidth(percent);
  return static_cast<uint8_t>((clamped - kPicoLfoMinPulseWidthPercent) /
                              kPicoLfoPulseWidthStepPercent);
}

inline uint8_t picoLfoPulseWidthPercentFromIndex(int index) {
  return clampPicoLfoPulseWidth(
      kPicoLfoMinPulseWidthPercent +
      clampValue<int>(index, 0, kPicoLfoPulseWidthStepCount - 1) *
          kPicoLfoPulseWidthStepPercent);
}

inline uint8_t clampPicoLfoLink(int value) {
  return static_cast<uint8_t>(clampValue<int>(value, 0, kPicoLfoLinkCount - 1));
}

inline uint8_t clampPicoLfoPhaseOffset(int value) {
  return static_cast<uint8_t>(clampValue<int>(value, 0, kPicoLfoPhaseOffsetCount - 1));
}

inline uint8_t clampPicoClockSource(int value) {
  return static_cast<uint8_t>(clampValue<int>(value, 0, kPicoClockSourceCount - 1));
}
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

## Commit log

2026-07-27 Initial release: Pico expression/CV controller for Therevox
    Raspberry Pi Pico H firmware with MCP4725 DAC output, SSD1306 OLED,
    rotary encoder UI, per-interval pitch map with response-fit calibration,
    pedal curves, host-side simulator and math tests, docs, BOM, and
    3D-printable enclosure.
2026-07-27 Mark enclosure design as untested
    The 3D-printed enclosure has never been printed or test-fitted; flag it
    clearly in the enclosure README, main README, and physical layout doc.
2026-07-27 Rewrite README: concise, drop bench-history narrative
    Retitle to match repo name, cut prototype test war stories, keep the
    practical build/calibrate/use info.
2026-07-27 Add LFO output modes; rename to Therevox Expression Controller
    LO (0.05-20 Hz) and FM (8-160 Hz) LFO modes with six waveforms,
    pedal-swept rate, encoder-controlled depth, polarity flip, phase sync,
    menu value pickers, serial commands, and host test/sim coverage.
    Product renamed to Therevox Expression Controller (repo URL unchanged).
    [PicoFirmwareCore.h, PrecisionExpressionControllerPico.ino, pico_console_sim.cpp]
2026-07-30 Add LFO feature suite and MCP4728 hardening
    Features: sample+hold and drift random waveforms, adjustable pulse width
    (5-95%), depth extended to 0-100% with -50..+50% center offset on the
    dedicated outputs, LFO2 rate-link to LFO1 (1:1/1:2/1:4/3:2/2:1/4:1) with
    0/90/180/270 phase offsets, tap tempo on encoder presses and serial,
    sync all, and a full-swing clock square on DAC channel D (clock lfo1|lfo2).
    Hardening: DAC writes switched to MCP4728 multi-write (UDAC=0) so outputs
    latch even with a floating LDAC pin and VREF=VDD/gain=1 is asserted on
    every update; new "dac eeprom" command programs 0V power-on defaults;
    settings version 12 migrates from v11 preserving calibration and the
    tuned toe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
    [PicoFirmwareCore.h, PrecisionExpressionControllerPico.ino, pico_console_sim.cpp]
2026-07-30 Add Therevox ET-5 sample patches doc
    Eleven patch recipes pairing the EXP/LFO1/LFO2/clock outputs with the
    ET-5 patch panel, with the serial settings for each; linked from the
    README and user manual.
2026-08-05 Clarify hardware docs and add enclosure baseplate
    - Standardize MCP4728 DAC pinout naming (A/B/C/D, V, S, DA, CL, L, R)
    across BOM, user manual, and firmware comments for clarity
    - Add open baseplate enclosure design (no walls, no lid)
    - Refine enclosure cutout specifications and perfboard footprint details
    - Update enclosure README with board dimensions and margin calculations
    Claude-Session: https://claude.ai/code/session_01RFWS1gkZyzjJo6ei1UHJ4n
    [expression_controller_baseplate.stl]
